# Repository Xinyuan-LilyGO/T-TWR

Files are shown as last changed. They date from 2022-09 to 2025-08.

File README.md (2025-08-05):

<h1 align = "center">🌟 LILYGO T-TWR 🌟</h1>




## News

#### There are the following differences between Rev2.1 and Rev2.0

1. Rev2.1 has a microphone switching matrix that can collect microphone signals for processing by ESP32S3, but Rev2.0 does not.
2. Rev2.1 has a speaker switching matrix, which can send audio signals to the power amplifier to play prompts, music, etc. through the switching matrix. Rev2.0 does not have it.
3. Rev2.1 has an IO switching matrix, and SA8X8 can be programmed through the switching matrix. Rev2.0 does not have this feature. This feature was proposed by the OpenRTX team. The function is not yet implemented. Please pay attention to OpenRTX for the latest progress.
4. Rev2.1 can determine whether the device address is UHF or VHF through OLED, but Rev2.0 cannot.
5. Rev2.1 can obtain whether the SA8X8 is currently in the receiving state by monitoring IO2, but Rev2.0 cannot..
6. In Rev2.1, the PTT button is changed to the left side, which is closer to the real walkie-talkie operating habits, while in Rev2.0, it is on the right side.
7. Rev2.1 changes the pixel light to the upper right to make it easier to monitor the status, Rev2.0 is on the side of the PCB
8. Rev2.1 reserves the RF front-end matching circuit, which makes it easier to fine-tune the signal.
9. The Rev2.1 RF module power supply is changed to direct battery power supply. Compared with the Rev2.0 DC power supply method, the power supply noise is minimized and can provide better RF performance.

## 1️⃣Support Product

| Product(PinMap) | SOC | Flash | PSRAM |
| --- | --- | ----- | --- |
| [T-TWR Rev2.0][1] | ESP32-S3R8 | 16MB  | 8MB(OPI) |
| [T-TWR Rev2.1][2] | ESP32-S3R8 | 16MB  | 8MB(OPI) |

[1]: https://www.lilygo.cc/products/t-twr-plus
[2]: https://www.lilygo.cc/products/t-twr-rev2-1

## 2️⃣Examples

```txt
examples/
├── Factory                         # TWR Factory Application
├── GPS_Basic_Example               # GPS example
├── GPS_Full_Example                # GPS example
├── Pixels_RGBWstrandtest           # Pixels example
├── Pixels_Strandtest_Example       # Pixels example
├── SA868_ATDebug_Example           # Radio  AT Debug example
├── SA868_ESPSendAudio_Example      # Radio frequency sends ESP32 signal
├── SD_Test_Example                 # SD Test Example
├── SD_Time_Example                 # SD Time Example
├── WAV_Player                      # WAV Player
├── TFT_ArcFill_Example             # Screen extension example
├── TFT_Keypad_240x320_Example      # Screen extension example
├── U8g2_FontUsage_Example          # Onboard OLED U8G2 example
├── U8g2_GraphicsTest_Example       # Onboard OLED U8G2 example
└── U8g2_UpdateArea_Example         # Onboard OLED U8G2 example
```

## 3️⃣ PlatformIO Quick Start

1. Install [Visual Studio Code](https://code.visualstudio.com/) and [Python](https://www.python.org/)
2. Search for the `PlatformIO` plugin in the `VisualStudioCode` extension and install it.
3. After the installation is complete, you need to restart `VisualStudioCode`
4. After restarting `VisualStudioCode`, select `File` in the upper left corner of `VisualStudioCode` -> `Open Folder` -> select the `T-TWR` directory
5. Click on the `platformio.ini` file, and in the `platformio` column, cancel the sample line that needs to be used, please make sure that only one line is valid
6. Click the (✔) symbol in the lower left corner to compile
7. Connect the board to the computer USB
8. Click (→) to upload firmware
9. Click (plug symbol) to monitor serial output

## 4️⃣ Arduino IDE Quick Start

1. Install [Arduino IDE](https://www.arduino.cc/en/software)
2. Install [Arduino ESP32](https://docs.espressif.com/projects/arduino-esp32/en/latest/)
3. Copy all the folders in the `T-TWR/lib` directory to `<C:\Users\UserName\Documents\Arduino\libraries>`. If there is no `libraries` directory, please create a new one. Please note that you are not copying the `lib` directory, but copying the folders in the lib directory
4. Open ArduinoIDE -> `Tools`
    | Arduino IDE Setting                  | Value                             |
    | ------------------------------------ | --------------------------------- |
    | Board                                | **ESP32S3 Dev Module**            |
    | Port                                 | Your port                         |
    | USB CDC On Boot                      | Enable                            |
    | CPU Frequency                        | 240MHZ(WiFi)                      |
    | Core Debug Level                     | None                              |
    | USB DFU On Boot                      | Disable                           |
    | Erase All Flash Before Sketch Upload | Disable                           |
    | Events Run On                        | Core1                             |
    | Flash Mode                           | QIO 80MHZ                         |
    | Flash Size                           | **16MB(128Mb)**                   |
    | Arduino Runs On                      | Core1                             |
    | USB Firmware MSC On Boot             | Disable                           |
    | Partition Scheme                     | **16M Flash(3M APP/9.9MB FATFS)** |
    | PSRAM                                | **OPI PSRAM**                     |
    | Upload Mode                          | **UART0/Hardware CDC**            |
    | Upload Speed                         | 921600                            |
    | USB Mode                             | **CDC and JTAG**                  |
    * The options in bold are required, others are selected according to actual conditions.
5. Insert USB into the PC and click Upload <If the upload fails, View the FAQ below>

## 5️⃣ FAQ

1. ⚠⚠⚠ **Precautions (special matters)**:
    1. The **glue stick (RF) antenna** must be connected. If the antenna is not connected, the RF module may be damaged, and the PMU will automatically turn off the power output
    2. A separate USB power supply may not meet the power supply requirements, please connect the battery to use , **The Rev2.1 version must use a battery to power the radio frequency unit and cannot use USB to work alone (because the RF current is very large and the noise can be minimized using battery power)**
    3. Please note that when adjusting to high power transmission, please ensure that the battery has sufficient discharge capacity, otherwise the PMU will automatically shut down due to insufficient current.
    4. TWR Rev2.0 has two versions, one comes with NiceRF AT firmware, and the other is a community version without any functions. For the community version, please jump to [OpenRTX](https://github.com/OpenRTX/OpenRTX) to burn [OpenRTX SA8x8 firmware](https://github.com/OpenRTX/sa8x8-fw) for use. For novices, it is recommended to use NiceRF firmware.
    5. TWR Rev2.1 is version agnostic. The built-in NiceRF firmware can be flashed to OpenRTX firmware, but the NiceRF firmware cannot be restored after flashing.

2. Radio extremely hot when sending?
      1. If the power level is set to high, then the current consumption is huge and the efficiency is very low. It is not recommended to use high power because the difference between high and low power is very small, but the difference in current consumption is very large. You can check the comparison here

      | Voltage | Freq | High transmit power                    | Low transmit power                   |
      | ------- | ---- | -------------------------------------- | ------------------------------------ |
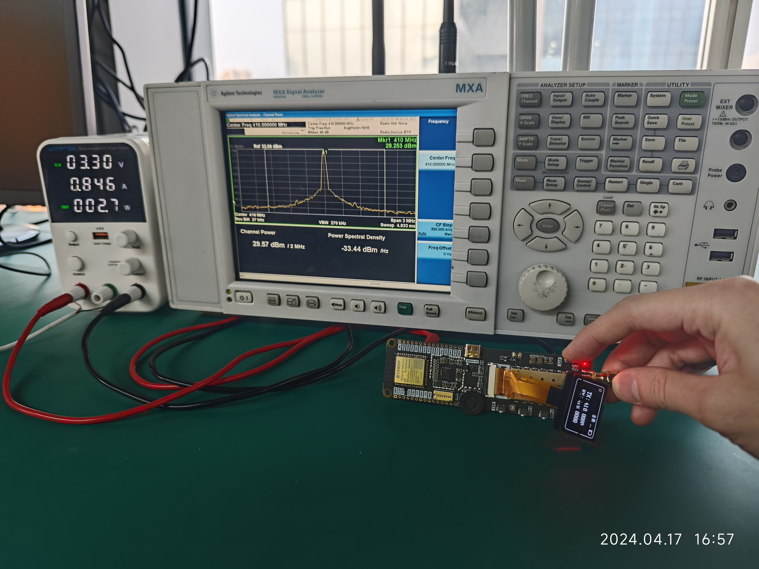
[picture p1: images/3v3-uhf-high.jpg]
UHF_HIGH
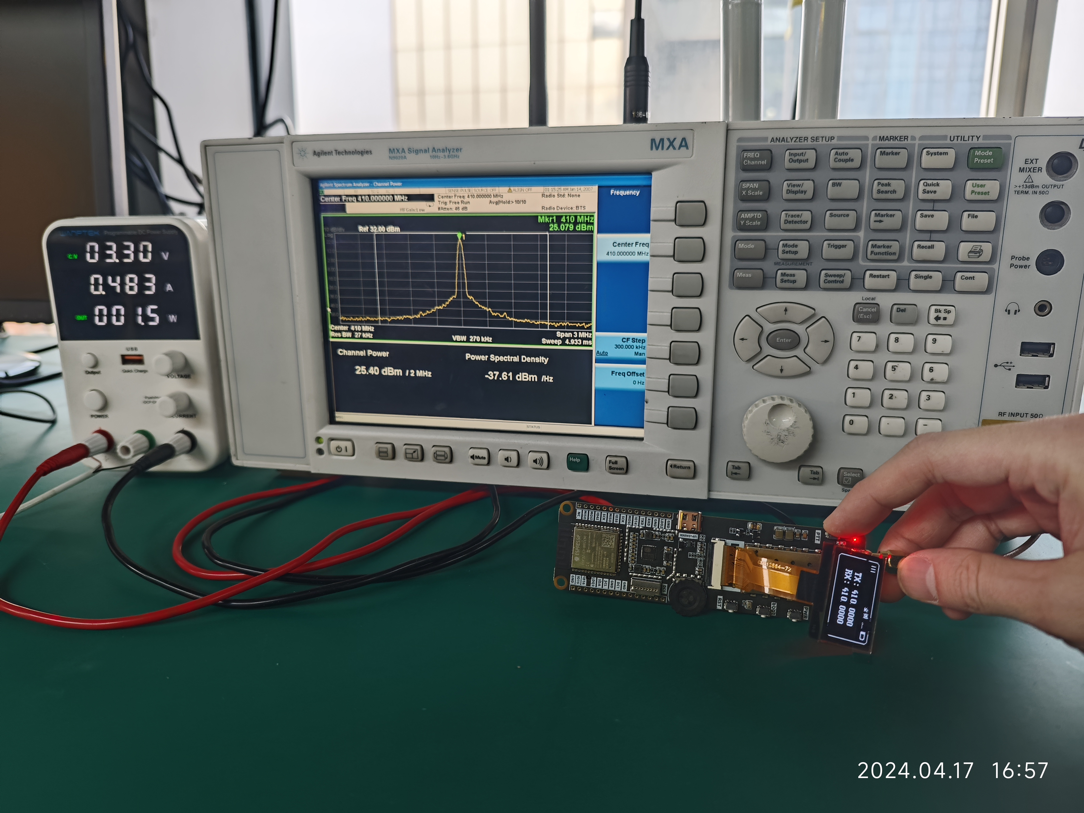
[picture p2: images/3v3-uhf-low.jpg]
      | 3.3V    | UHF  |  |  |
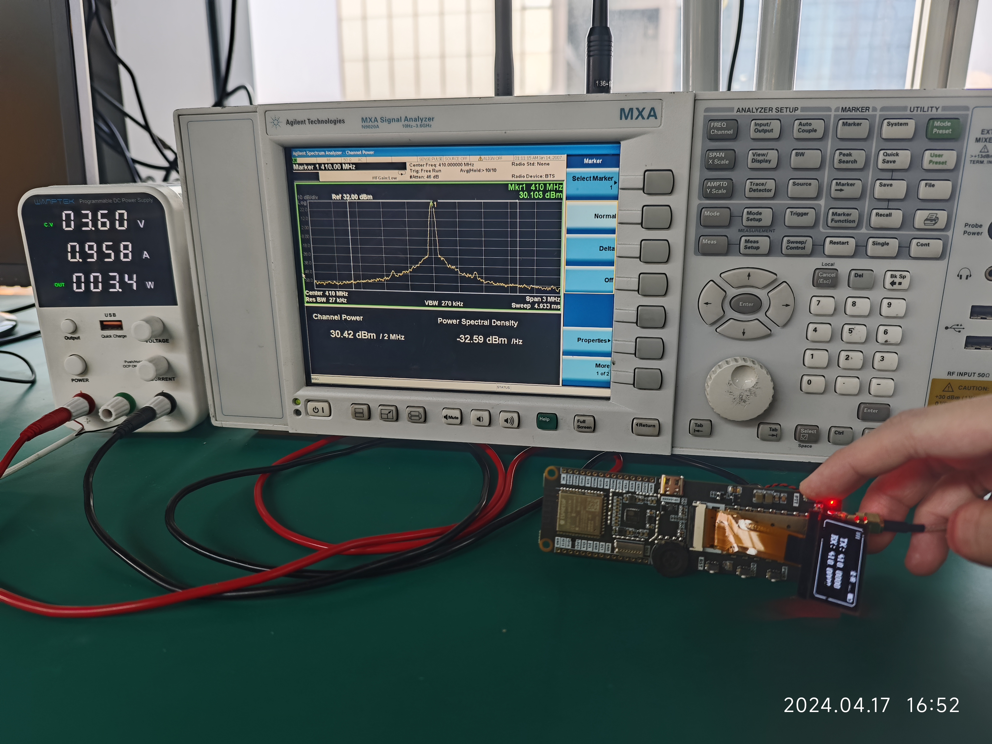
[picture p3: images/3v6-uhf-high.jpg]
UHF_HIGH
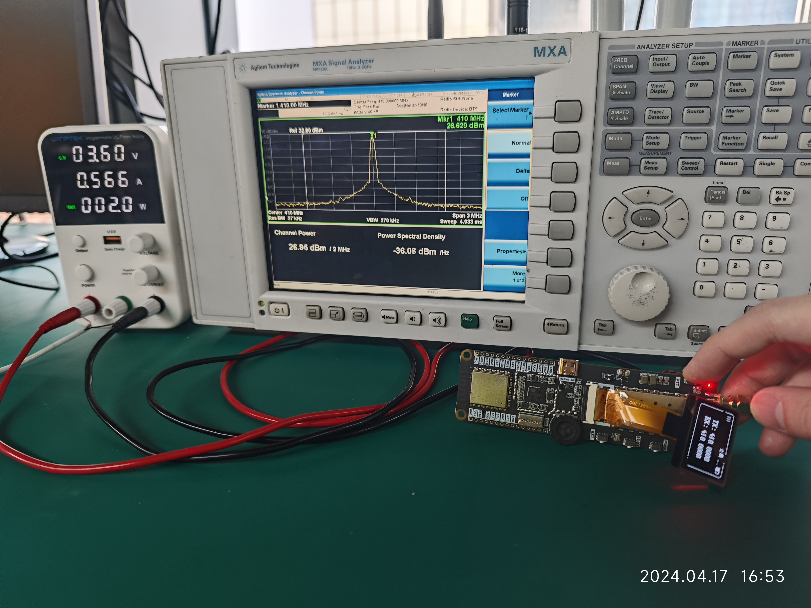
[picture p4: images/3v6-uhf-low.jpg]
      | 3.6V    | UHF  |  |  |
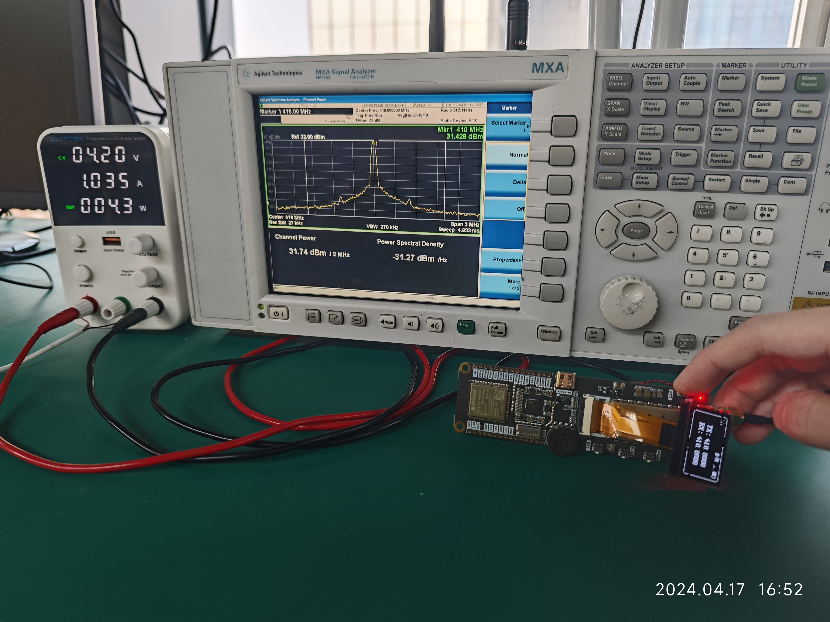
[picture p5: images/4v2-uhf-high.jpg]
UHF_HIGH
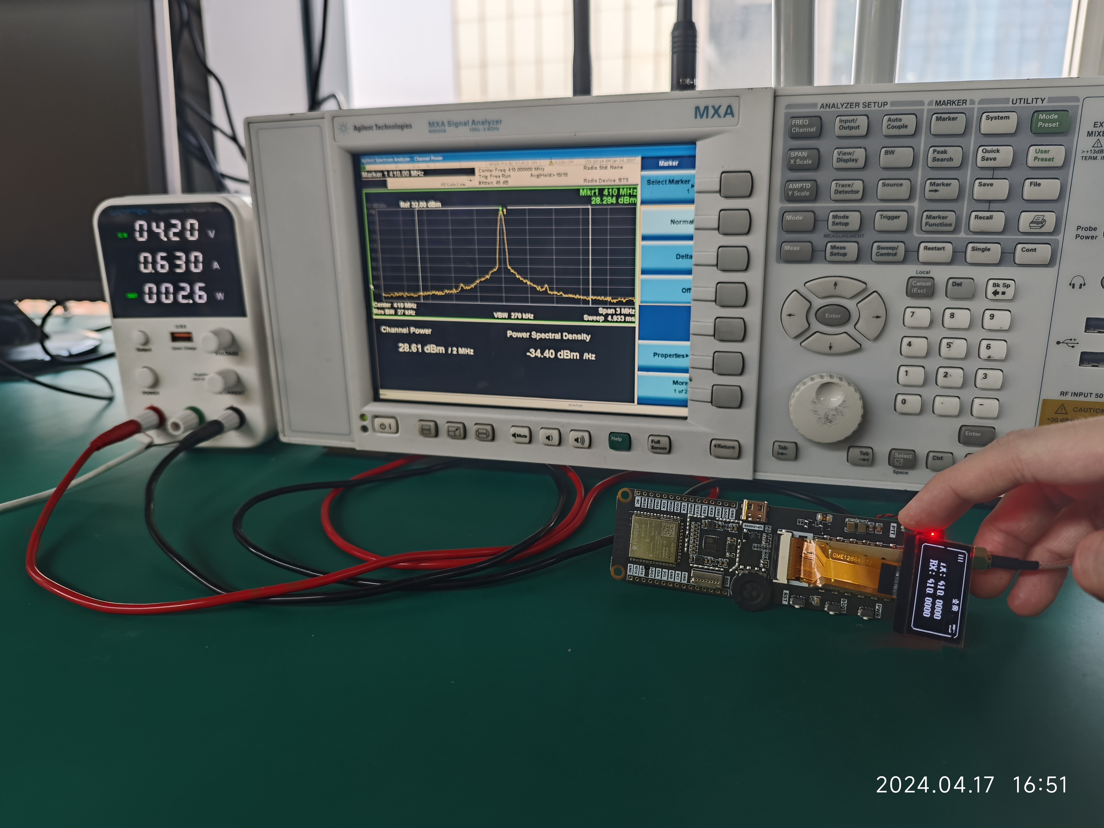
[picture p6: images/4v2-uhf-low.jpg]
      | 4.2V    | UHF  |  |  |
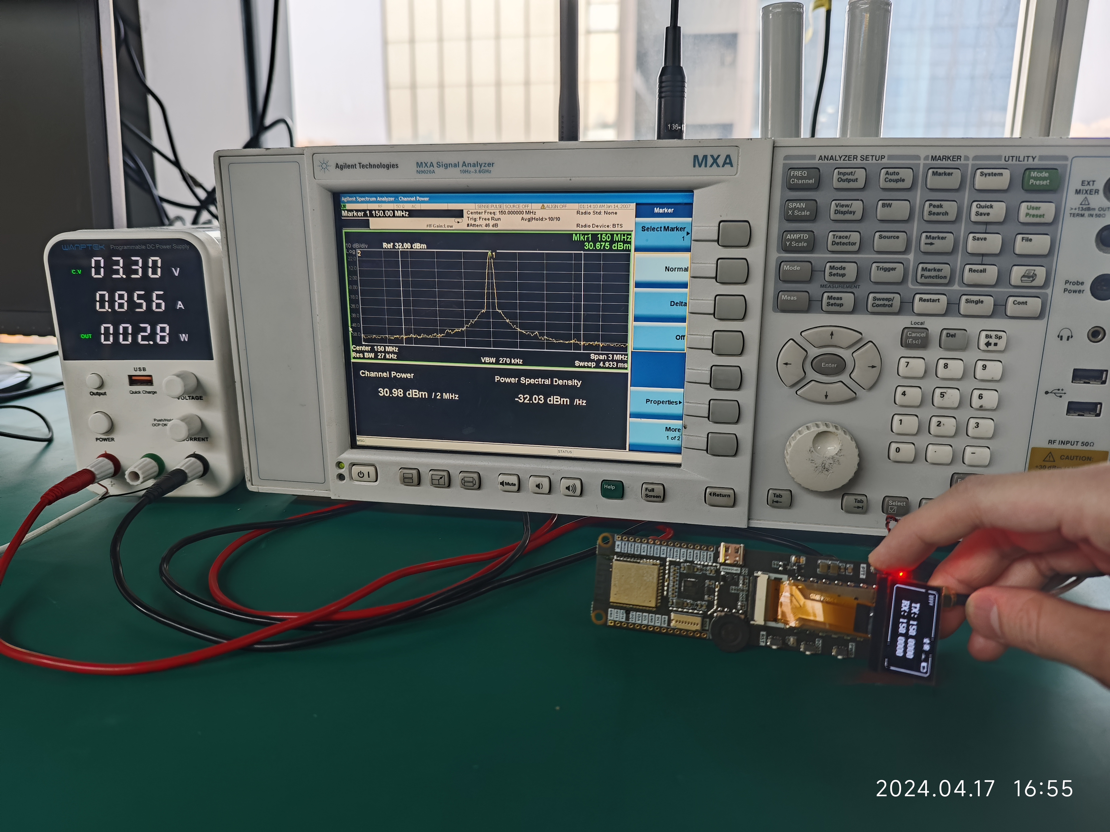
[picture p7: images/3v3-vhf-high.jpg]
VHF_HIGH
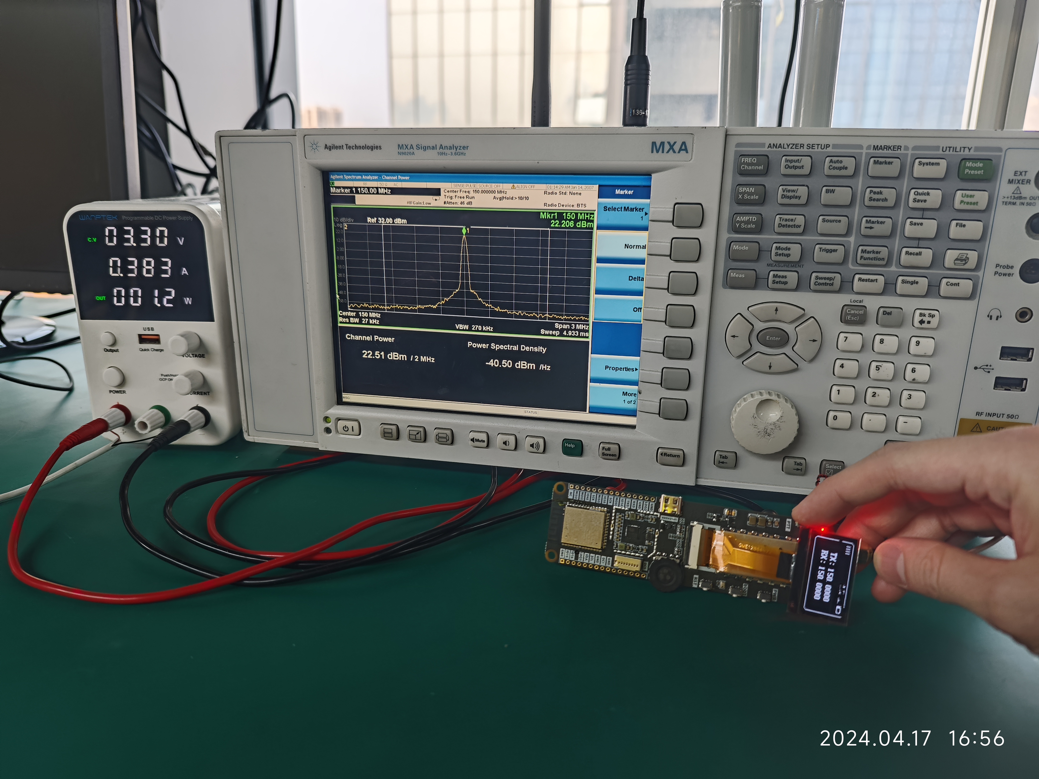
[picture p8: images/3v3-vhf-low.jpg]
      | 3.3V    | VHF  |  |  |
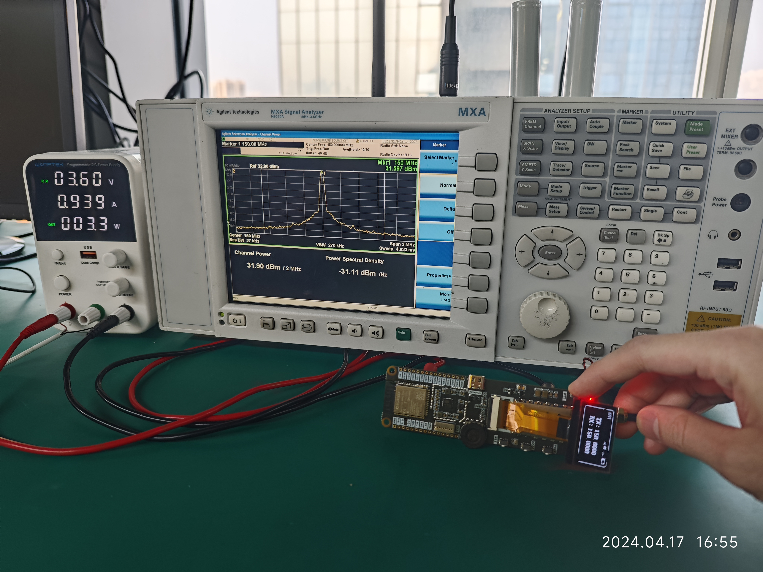
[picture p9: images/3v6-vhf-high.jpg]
VHF_HIGH
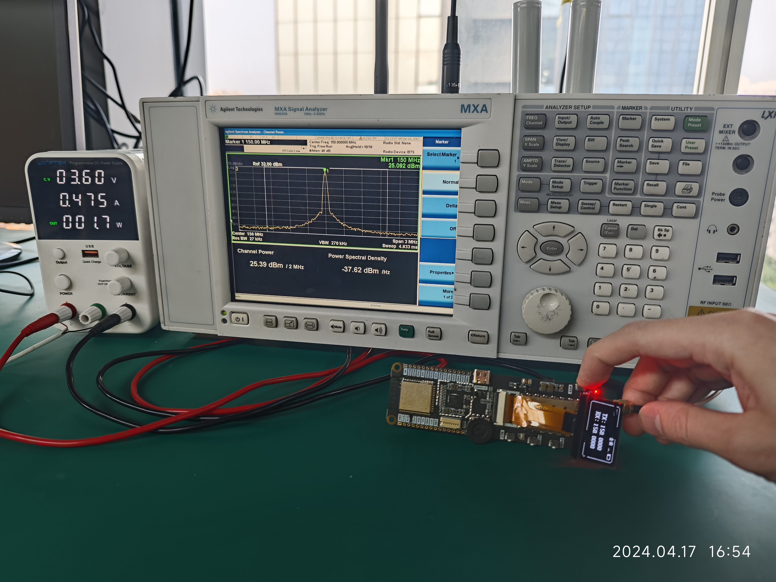
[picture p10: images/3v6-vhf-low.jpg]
      | 3.6V    | VHF  |  |  |
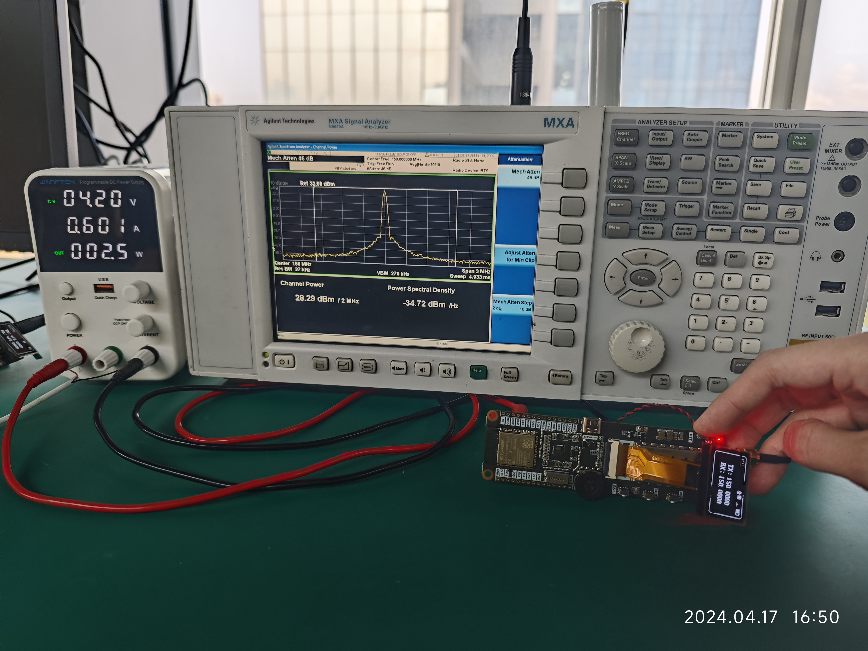
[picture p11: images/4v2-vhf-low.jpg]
      | 4.2V    | VHF  |   | VHF_LOW |

 3. ⚠ **Unable to download the program, the error is shown below.**
      <details>
      <summary>
      Click to view detailed steps
      </summary>

      ```shell
      Flash: [====      ]  35.7% (used 467813 bytes from 1310720 bytes)
      Configuring upload protocol...
      AVAILABLE: cmsis-dap, esp-bridge, esp-builtin, esp-prog, espota, esptool, iot-bus-jtag, jlink, minimodule, olimex-arm-usb-ocd, olimex-arm-usb-ocd-h, olimex-arm-usb-tiny-h, olimex-jtag-tiny, tumpa
      CURRENT: upload_protocol = esptool
      Looking for upload port...
      Auto-detected: COM236
      Uploading .pio\build\uhf_band\firmware.bin
      esptool.py v4.5
      Serial port COM236
      Connecting...

      A serial exception error occurred: ClearCommError failed (PermissionError(13, 'The device does not recognize the command.', None, 22))
      Note: This error originates from pySerial. It is likely not a problem with esptool, but with the hardware connection or drivers.
      For troubleshooting steps visit: https://docs.espressif.com/projects/esptool/en/latest/troubleshooting.html
      *** [upload] Error 1
      ================================================================================================================ [FAILED] Took 8.75 seconds ================================================================================================================

      ```
      - Step
      - Press the **PWR** button for one second to make sure the TWR is powered on
      - Press and hold the **BOOT** button (without releasing it), then press the **RST** button, then release the **RST** button, and finally release the **BOOT** button
      - Click the upload button in the IDE and wait for the upload to complete
      - Press the **RST** button to exit the download mode
      
      </details>

3. ⚠ **Can I change the voltage of the peripheral?**
      <details>
      <summary>
      Click to view detailed steps
      </summary>
        1. Not recommended, changing the peripheral voltage may cause abnormal operation, please do not change the default voltage setting of the peripheral, please refer to the voltage setting in the sample program.
      </details>

4. ⚠ **Why can't I test the charging current to reach the set current?**
      <details>
      <summary>
      Click to view detailed steps
      </summary>
       1. If you use a USBC cable with low quality or too large or too long wire resistance, there will be a large internal resistance, and there is no rated 5V input on the board, so the PMU will think that the power supply voltage is insufficient, so the rated charging current cannot be reached. ,The solution is to replace the high-quality USBC wire, reduce the length of the wire to meet the requirements of the PMU input voltage<br>
       2. You can measure the voltage at both ends of the figure below to see if it can meet the 5V input voltage required by the PMU<br>
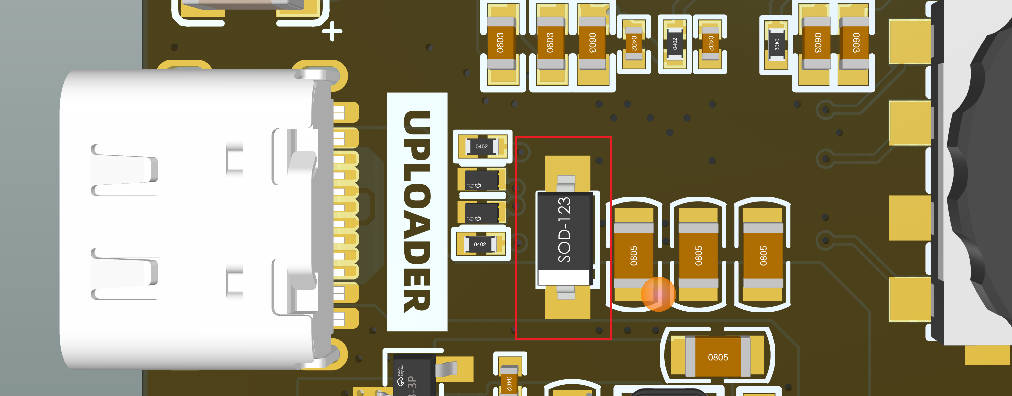
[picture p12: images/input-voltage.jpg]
         

      1. Please note that if the charging current is set to 1A, please install a suitable heat sink above the PMU to reduce the risk of heat and damage caused by overheating.
      </details>

5.  ⚠  When you think there is a problem with the board, you can try to burn our [factory firmware](./firmware/README.MD) for testing, you can first rule out whether it is a hardware problem

6. ⚠ **I don’t have a **21700 battery**, can I replace the battery holder with a **18650** battery holder?**
      <details>
      <summary>
      Click to view detailed steps
      </summary>
      1. The board is compatible with 21700 and 18650 battery holders, if you have the ability to replace it, please note that **LilyGo does not bear the risk of replacing the battery holder without authorization, damage and Brought to work abnormally**
      </details>

7. ⚠ **Can't turn on automatically after connecting the battery?**
      <details>
      <summary>
      Click to view detailed steps
      </summary>
      1. Connect the battery separately, you need to press the **PWR button** for one second, the board will start the action, press and hold the **PWR** button for 6 seconds to shut down, the shutdown time can be set by software , In the latest version (Rev2.1), inserting the battery will automatically power on.
      </details>

8. TWR currently has two modes before leaving the factory, one is flashed with regular firmware and uses the esp built-in boot, and the other uses TinyUF2 as the boot program. For novices, please [see here](./firmware/README.MD)

9.  How to enter TinyUF2 boot mode?

      <br>

      <details>
      <summary>
      Click to view detailed steps
      </summary>
       1. Before entering TinyUF2, the boot program must have been flashed. If it has not been written, please see here https://github.com/Xinyuan-LilyGO/T-TWR/blob/master/firmware/README.MD <br>
       2. Press the RST button<br>
       3. After pressing the RST button for one second, press the BOOT button. The disk will be ejected on the computer.<br>
       4. At this time, drag the firmware with the suffix uf2 into the disk to upgrade the device.<br>
      </details>
11. ⚠ **There is a microphone port on the bottom of the board, do I need to install a microphone? Only for Rev2.0, Rev2.1 has removed the external microphone interface**
      <details>
      <summary>
      Click to view detailed steps
      </summary>
      1. No, there is already a condenser microphone on board. If you need to use a wired microphone, please remove the board microphone. Please note that **LilyGo will not be responsible for the damage and abnormality of the board caused by unauthorized disassembly of the microphone**
      </details>

12. Sleep power consumption (**Rev2.1**), taking the Factory example as a reference, the deep sleep current is about **680uA**
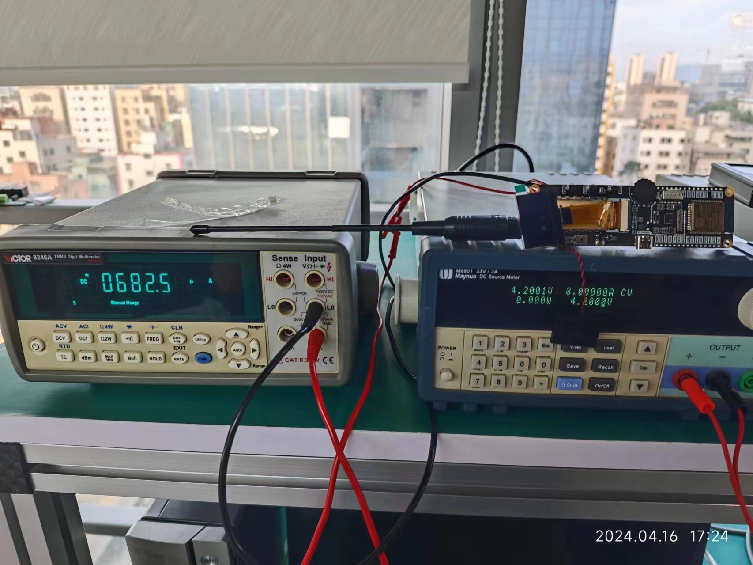
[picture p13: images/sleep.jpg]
      <br>

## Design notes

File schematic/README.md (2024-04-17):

# Schematic

| Version Information | Schematic |
| --- | --- |
| T-TWR Plus Rev 2.0 | [T-TWR_Plus Rev2.0](T-TWR-Plus_Rev2.0.pdf) |
| T-TWR Plus Rev 2.1 Preview | [T-TWR-Plus_Rev2.1-Preview](T-TWR-Plus_Rev2.1-Preview.pdf) |
| T-TWR Plus Rev 2.1 | [T-TWR_Plus Rev2.1](T-TWR-Plus_Rev2.1.pdf) |

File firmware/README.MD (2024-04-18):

# News
  
* For TWR Rev2.1, there is no need to distinguish between UHF or VHF, you can write directly to twr_Rev2.x.bin or **twr_Rev2.x.uf2**
* TWR Rev 2.0 can also be written to **twr_Rev2.x.bin** or **twr_Rev2.x.uf2**. The default is UHF. UHF or VHF can be selected through the menu.

# 1️⃣ Regular firmware

| FileName | Firmware |
| --- | --- |
| twr_Rev2.0_uhf.bin | [firmware](./twr_Rev2.0_uhf.bin) |
| twr_Rev2.0_vhf.bin | [firmware](./twr_Rev2.0_vhf.bin) |
| twr_Rev2.x.bin | [firmware](./twr_Rev2.x.bin) |
| twr_gps_debug.bin  | [firmware](./twr_gps_debug.bin)  |

## How falsh *.bin file ?

1. [Win10 Flash method](https://github.com/Xinyuan-LilyGO/LilyGo-Document/blob/master/WinFlashBin.md)
2. [Mac & Liunx Flash method](https://github.com/Xinyuan-LilyGO/LilyGo-Document/blob/master/MacFlashBin.md)

# 2️⃣ TinyUF2 firmware

| FileName | Firmware |
| --- | --- |
| tinyuf2_bootloader.bin | [firmware](./tinyuf2_bootloader.bin) |
| twr_Rev2.0_uhf.uf2 | [firmware](./twr_Rev2.0_uhf.uf2) |
| twr_Rev2.0_vhf.uf2 | [firmware](./twr_Rev2.0_vhf.uf2) |
| twr_Rev2.x.uf2 | [firmware](./twr_Rev2.x.uf2) |
| twr_gps_debug.uf2 | [firmware](./twr_gps_debug.uf2) |

* To use TinyUF2, you need to burn tinyuf2_bootloader.bin first. After the burning is completed, a disk will pop up. Drag firmware.uf2 into the disk.

## How to use ArduinoIDE to flash firmware again?

* After using TinyUF2, a virtual port will be generated and cannot be written directly using ArduinoIDE. The TWR must be put into download mode before the actual physical port will be displayed.
  
## How to put TWR into download mode

* Press the **PWR** button for one second to make sure the TWR is powered on
* Press and hold the **BOOT** button (without releasing it), then press the **RST** button, then release the **RST** button, and finally release the **BOOT** button
* Click the upload button in the IDE and wait for the upload to complete
* Press the **RST** button to exit the download mode

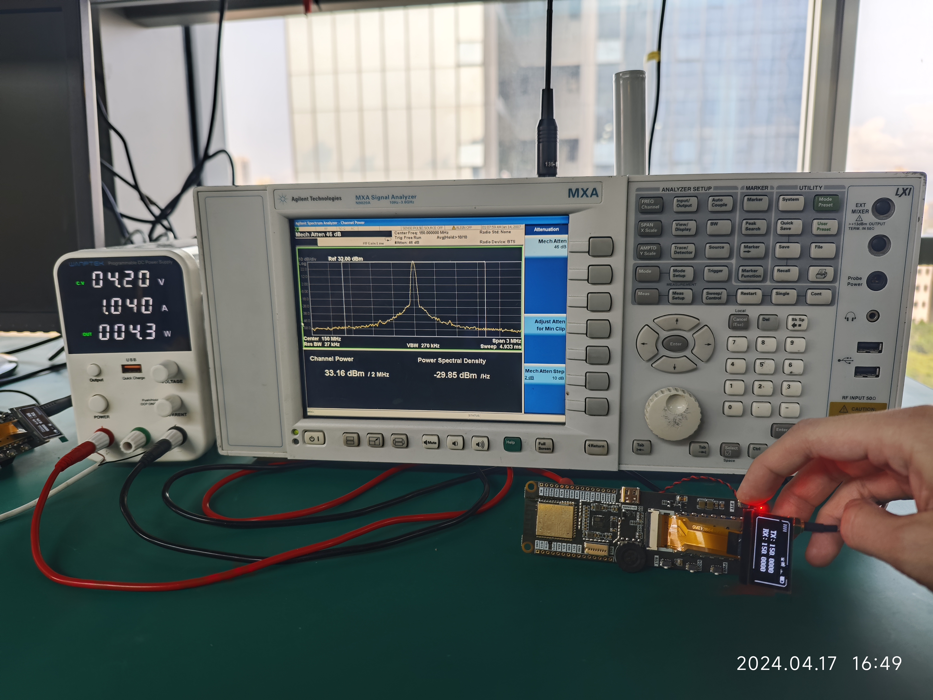
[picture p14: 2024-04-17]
images/4v2-vhf-high.jpg

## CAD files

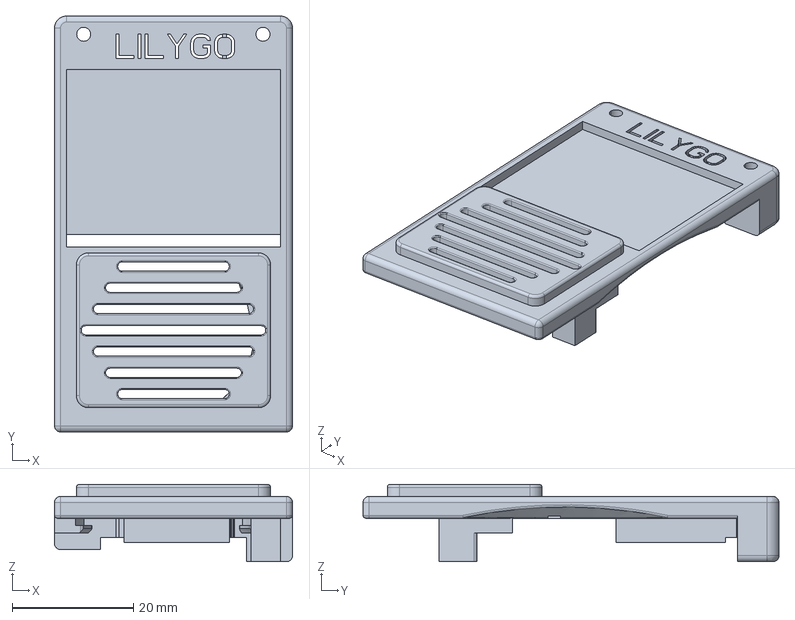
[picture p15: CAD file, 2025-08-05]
dimensions/TWR-Plus-Rev2.1-Display-shell.stp
39.2 x 68.5 x 12.8 mm

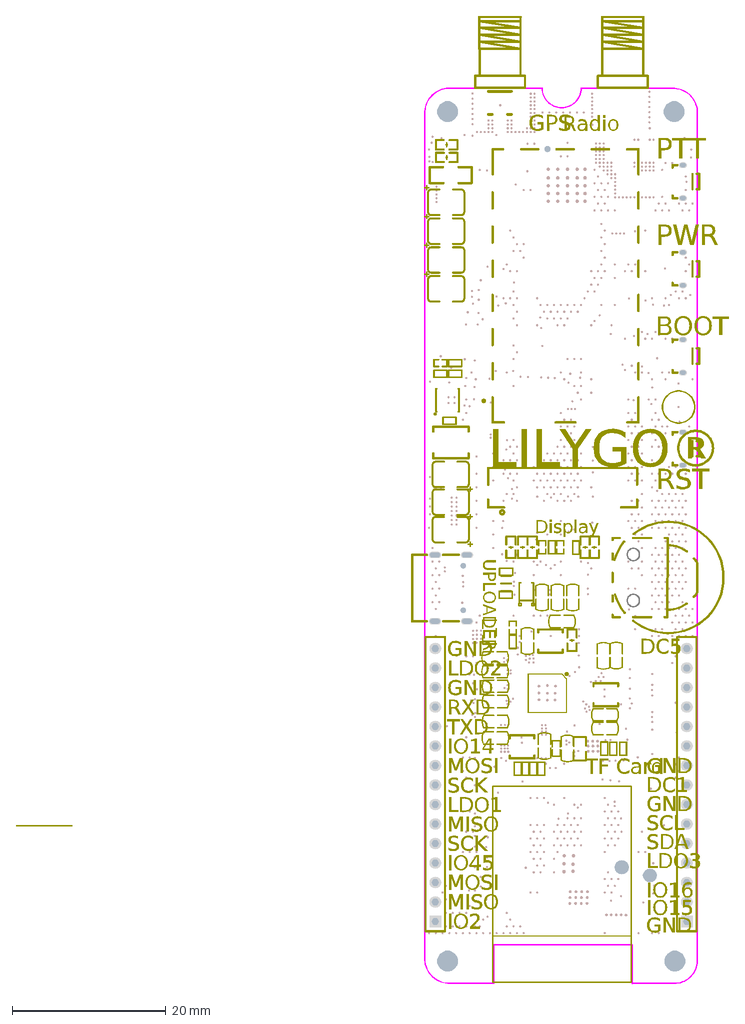
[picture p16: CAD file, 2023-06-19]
dimensions/TWR_Plus_Rev2_0.DXF
BOOT
TF Card
MOSI
GND
PTT
DC1
IO14
LDO1
SCK
SCL
IO2
MISO
RXD
LDO2
Display
UPLOADER
IO15
SDA
TXD
Radio
IO45
LILYGO®
RST
GPS
DC5
IO16
PWR
LDO3

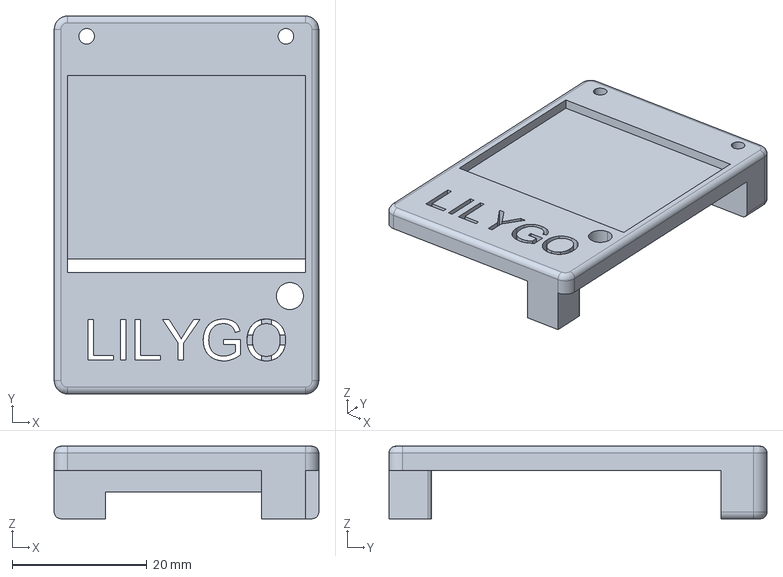
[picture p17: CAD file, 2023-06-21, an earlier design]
dimensions/TWR-Plus-Display-shell.stp
39.2 x 56.0 x 10.8 mm

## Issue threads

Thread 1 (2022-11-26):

ADC (SPK)  and DAC (MIC) feature request

lyusupov, 2022-11-26:
&nbsp;&nbsp; &nbsp; &nbsp;  Dear LilyGO T-TWR product developer !

Thank you very much for the idea and development of the T-TWR !

This message is actually not an issue report but a minor feature request...

I am not able to see the product schematics but can inspect the picture that was recently published on LilyGO Twitter account:

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

On this picture I can not see any electronic elements that would prove a statement that MIC and SPEAKER pads of the SA868 module are connected to the ESP32-S3 ADC/DAC ones.
So I assume that they are connected directly to the microphone and speaker components only, right?

If this is true - I have a minor design improvement proposal to you:
Could you, please, add few circuits to wire MIC and SPEAKER pads of the SA868 module to  ADC/DAC pads of the ESP32-S3 ?

There is a great project on GitHub https://github.com/erstec/APRS-ESP
that uses both SA868  and ESP32 where:
*  ESP32 can supply signal to SA868 (DAC to MIC) and
*  ESP32 can read signal from SA868 (SPK to DAC)

This is an excerpt of the schematics that you can use as a reference:

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

While having this feature available, we can:
* record the received radio signal into 16 Mbytes flash memory of the ESP32-S3 module and/or
* play sound recordings from flash memory and transmit them into the RF air

    Best regards,
    Linar.

lbuque, 2022-12-10:
Hi,
Presumably you have received the schematic diagram of T-TWR!

Your idea is great, but whether those functions will be added needs confirmation from the leadership!

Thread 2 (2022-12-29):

T-TWR RF module connect audio to ESP32

redfast00, 2022-12-29:
Hi! I'd be really excited to use the T-TWR module for digital HAM radio projects (for example as an APRS modem). Is the RF chip directly connected to the microphone/speaker? Is it possible to send and receive audio waveforms from/to the ESP32?

redfast00, 2022-12-29:
This would for example also make it possible to build an internet-connected radio repeater

lbuque, 2022-12-30:
> Is the RF chip directly connected to the microphone/speaker?

yes.

> Is it possible to send and receive audio waveforms from/to the ESP32?

Newer hardware may support it.

lyusupov, 2023-05-27:
> Is it possible to send and receive audio waveforms from/to the ESP32?

https://github.com/Xinyuan-LilyGO/T-TWR/blob/master/schematic/T-TWR-Plus_Rev2.0.pdf

> excited to use the module for digital HAM radio projects (for example as an APRS modem)

https://github.com/erstec/APRS-ESP

Closed 2024-02-11.

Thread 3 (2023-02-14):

T-TWR 3D model case and schematic

kkwestt, 2023-02-14:
Please add T-TWR 3D model case and schematic. Thx

lbuque, 2023-02-16:
@kkwestt The schematic diagram has been uploaded, and the 3d model still needs time.

F4VSJ, 2023-04-18:
Well since February 16th, still no 3d printable case available?
I'm not able to design, sorry

lewisxhe, 2023-04-21:
Currently, there is still no

EasyOne2030, 2024-01-07:
**T-TWR 3D model case ?**

Closed 2024-02-21.

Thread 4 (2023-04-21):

print_wakeup_reason' was not declared in this scope

EasyOne2030, 2023-04-21:
exit status 1
'print_wakeup_reason' was not declared in this scope
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

lewisxhe, 2023-04-22:
Add this line above the sketch

void print_wakeup_reason();

EasyOne2030, 2023-04-22:
The problem is not solved !
exit status 1
'app_nvs_init' was not declared in this scope

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

lewisxhe, 2023-04-22:
Already fixed.

https://github.com/Xinyuan-LilyGO/T-TWR/commit/1597e8b1bccb8b3283aace25060cdb846f4086b7

Closed 2023-04-22.

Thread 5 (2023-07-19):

PTT button is not turn on transmission

nmuntyanov, 2023-07-19:
Hello, guys!
I've bought TWR Plus 2.0 VHF version, and found few bugs (or not, not shure)

1 transmit/receive frequency can't be changed with encoder via settings menu
I have build firmware in debug mode, and see that new frequency is sent to SA868 but there is still old one on LCD screen

2 there is no transmission when PTT button is pressed
I have added Serial.print in void SA868::transmit() function to be able to debug that it is invoked and it does, but no transmission happened (I have SDR to monitor)

Is anyone have such issues? Any solutions?

And one more thing, how can i suppress such log types:
```
$GNGSA,A,3,09,14,42,,,,,,,,,,5.1,3.8,3.4,4*36
$GPGSV,2,1,06,07,39,061,19,08,12,052,23,09,12,119,30,13,42,305,,0*6D
$GPGSV,2,2,06,14,60,156,33,15,11,306,,0*63
$BDGSV,1,1,03,09,12,0840,E,1,07,3.8,605.8,M,43.9,M,,*4F
$GNGLL,4238.92078,N,02322.91040,E,200244.000,A,A*43
$GNGSA,A,3,07,08,09,14,,,,,,,,,5.1,3.8,3.4,1*3A
$GNGSA,A,3,09,14,42,,,,,,,,,,5.1,3.8,3.4,4*36
$GPGSV,2,1,06,07,39,061,19,08,12,052,25,09,11,119,30,13,42,305,,0*68
$GPGSV,2,2,06,14,60,156,33,15,11,306,,0*63
$BDGSV,1,1,03,09,12,082,23,14,49,162,31,42,24,152,39,0*45
$GNRMC,200244.000,A,4238.92078,N,02322.91040,E,0.31,0.00,180723,,,A,V*03
```
they are not informative for me now

amoxu, 2023-07-19:
The logs are from GPS module.

When you placed the order,  Which edition you selected? open edition or standard edition?

nmuntyanov, 2023-07-19:
> The logs are from GPS module.
>
> When you placed the order, Which edition you selected? open edition or standard edition?

I've bough here https://www.aliexpress.com/item/1005005734253889.html
OpenEdition VHF
Order placed on: Jun 29, 2023

nmuntyanov, 2023-07-19:
But there is no "OpenEdition" word on box
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
what is the difference?

amoxu, 2023-07-19:
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

You need to read about the NOTICE on the product page,  Open edition is a special edition which with blank RF module,  It will be useful only after open source firmwares released,  Which are under very early development stage.

Welcome to pay attention to the progress of M17 and OPENRTX projects.

nmuntyanov, 2023-07-19:
Got it! Thank you.
Do you have links on this projects?

amoxu, 2023-07-19:
> Got it! Thank you.
> Do you have links on this projects?

https://discord.gg/k4deHPZy

nmuntyanov, 2023-07-19:
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

Thank you. I thought there are no firmware for sa868 at all
Can I somehow burn it into module without soldering it?
As I understand module is Connected to only ESP32 by UART?
Can it be programmed in-system?

nmuntyanov, 2023-07-19:
> Thank you. I thought there are no firmware for sa868 at all Can I somehow burn it into module without soldering it? As I understand module is Connected to only ESP32 by UART? Can it be programmed in-system?

I guess, i found
It seems CN4 socket is for sa868 programming

amoxu, 2023-07-21:
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

Yes, for more details, please refer to the discussions in the discord channel.

nmuntyanov, 2023-07-29:
> https://discord.gg/k4deHPZy

May you send me new invite? Old one is expired
I had some issues with my discord account before.

amoxu, 2023-07-30:
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

https://discord.gg/K4y5DxeBG

you can also following matrix space:
https://matrix.to/#/#openrtx:matrix.org
All the messages are synchronized between matrix and discord.

Closed 2023-07-19.

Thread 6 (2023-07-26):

Programming issue

itay-grudev, 2023-07-26:
I have two T-TWR, rev 1 and I can't program any of them.

I followed your reset procedure in the troubleshooting section, but when I do that the serial device disappears from the USB Device list.

Do you have any other advice?

lyusupov, 2023-07-27:
> **T-TWR, rev 1** , I can't program any of them.

- https://t-twr.readthedocs.io/en/latest/troubleshooting.html#sa868-power-problem
- https://docs.espressif.com/projects/esp-idf/en/latest/esp32s3/api-guides/jtag-debugging/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

itay-grudev, 2023-07-29:
@lewisxhe As I said, when I follow that procedure the device disappears from the USB. It's very strange and I can't upload anything.

SensorsIot, 2023-08-22:
My two boards also create lots of problems. If I follow your advice and reset it with GPIO0 pressed, the board draws 1.7A, and the SA868 gets extremely hot (but no output power on RF). I managed to program one board using RX/TX pins. The other one only creates brownouts (also with a battery attached).

lyusupov, 2023-08-25:
Version **1**.x of T-TWR uses GPIO39 to drive H/L pin of SA868 module.
Unfortunately, it is not well documented by Espressif that GPIO39 has hardware  pull up after reset to meet some JTAG MTCK purpose requirements.

https://www.esp32.com/viewtopic.php?f=12&p=111105

This _(not well documented)_ pull-up state can cause an excessive heat of SA868 module until it is explicitly set to LOW by a customer's firmware.
**LilyGO factory firmware pulls the GPIO39 down at very first steps of it's initialization sequence**.

OpenOCD firmware uploading method is knowing good to operate with T-TWR 1.3:
https://docs.espressif.com/projects/esp-idf/en/latest/esp32s3/api-guides/jtag-debugging/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

**This issue is not applicable for version 2.x** of the T-TWR which is also known as **T-TWR Plus**.

Here is an example of the **T-TWR Plus** operating as [**APRS Beacon**](https://en.wikipedia.org/wiki/Automatic_Packet_Reporting_System) device.
https://drive.google.com/file/d/18a2PpIE4KQ6lYPcmPZgXnCYFSRYEqKz-/view

A bit more info about this particular use case is available there: https://github.com/lyusupov/SoftRF/wiki/Ham-Edition

SensorsIot, 2023-08-25:
I think that these boards are not fit for purpose and I will throw my 4 pcs into the waste. If you sell such a product with Arduino software it should be programmable with Arduino SW.
The problem with the high current starts when you set the board into the upload status (press boot + reset), which is needed in many cases for programming. I do not exactly know why. Most probably not only because of GPIO39. H/L has no function in the RX mode of the SA868 module.
For all that that want to use them anyway: Use RX/TX for programming instead of USB. Reset the board and wait till the Arduino IDE starts to upload. Then press boot and quickly reset. Now it uploads, and the module warms up. Immediately after upload, reset the board, and if you set PTT and H/L to low, as written above, the board is not boiling. If you set the Arduino parameters correctly, it might even be possible to program it with USB from now on.

lyusupov, 2023-08-25:
> I think that these boards are not fit for purpose

It was reported by LulyGO that the engineer who designed T-TWR **1.3** no longer works for that company. Some online stores may still sell stocks of v1.3 boards remaining...

**T-TWR Plus**  (a.k.a. v2.0) is supported by Adafruit **TinyUF2** bootloader since 0.16.0:
https://github.com/adafruit/tinyuf2/releases/tag/0.16.0
Read this PR for details: https://github.com/adafruit/tinyuf2/pull/337

**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**

Installing a new firmware into T-TWR Plus with pre-installed TinyUF2 is as simple as mouse "drag and drop" in a File Manager.
https://github.com/lyusupov/SoftRF/blob/master/software/firmware/binaries/README.md#esp32-s3

SensorsIot, 2023-08-26:
Unfortunately, this is not entirely true. Just checked and the official Lilygo Store still sells the old version.

SensorsIot, 2023-08-28:
BTW: I just saw your name on my new T-Echo. If you are responsible for it: Congratulations! It should appear in one of my next videos

lyusupov, 2023-08-28:
**T-Echo** is a result of collaboration of **LilyGO** with
- [SoftRF project](https://github.com/lyusupov/SoftRF) and
- [Meshtastic project](https://meshtastic.org/) , https://meshtastic.discourse.group/t/exciting-new-ttgo-board-prototype/1399/50

**Lewis** is the LilyGO leading engineer who were driving force for development of the T-Echo in 2020 / 2021.

https://github.com/Xinyuan-LilyGO/T-TWR/issues/6#issuecomment-1653663379

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

**Lewis** is driving development of T-TWR **V2.x** (a.k.a. Plus) series at this time.

lewisxhe, 2023-08-28:
Hi @SensorsIot ,

If you encounter problems during use, please contact customer service for processing.

iontodirel, 2025-02-08:
does not work for me, and now it's bricked with a blank screen 👎 any idea of alternate ways to flash it?

Closed 2024-02-11.

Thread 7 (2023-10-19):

Frequency tuning

dnwk, 2023-10-19:
For the walkie-talkie example, I am trying to figure out where is it that controls the TX/RX frequency config. I want to be able to tune to 147.240. Currently, if bandwidth is set to 25k, that also make tuning in 25k increment.

SpudGunMan, 2024-02-03:
is this firmware intended for the VHF unit?

SpudGunMan, 2024-03-04:
Boop

lewisxhe, 2024-04-17:
No, it can only be superimposed in increments of 12.5 or 25, which is stated in the specification.

lewisxhe, 2024-04-17:
https://github.com/Xinyuan-LilyGO/T-TWR/blob/master/datasheet/SA868%202W%20Embedded%20walkie%20talkie%20moduleV1.3.pdf

lyusupov, 2024-04-18:
Unlike SA818 and SA828, the **SA868** module _( with NiceRF firmware )_ is a "**12.5 KHz bandwidth only**"  device:

<br>

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

Closed 2024-06-02.

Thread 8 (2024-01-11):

Can't turn on T-TWR 2.0

nmuntyanov, 2024-01-11:
Hello guys! Can you help me, please.

Version:  2.0, Open edition
I have used it a little bit and now i can't turn it on with pwr button with battery installed.
It works with external power supply and I can turn it on/off with button, and even battery level works (in case when battery + external power supply)

What it can be? Should I replace AXP2101?

lewisxhe, 2024-01-11:
Can't turn on when using battery alone?

nmuntyanov, 2024-01-11:
there is some electric noise, PWM i guess, when I press the pwr button

lewisxhe, 2024-01-12:
Do you have a multimeter? After pressing PWR, does DC1 on both sides of the pin header have 3.3V?

lewisxhe, 2024-01-12:
If you have the tools, we can continue to find the problem. If not, please contact customer service to see how to proceed.

nmuntyanov, 2024-01-12:
I have multimeter
Measurements are:
0,52v before and 0,17v after button press

lewisxhe, 2024-01-16:
Hi， @nmuntyanov
What I mean is that after pressing the PWR button, is there 3.3V on the pins marked DC1 on both sides of the TWR?

nmuntyanov, 2024-01-16:
Hi, @lewisxhe
Just to clarify

If you mean this pin
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

No, there is no 3,3v between DC1  and GND after PWR button is pressed

lewisxhe, 2024-01-16:
@nmuntyanov
Okay, I also need to check the following points with you to help me determine the approximate location of the fault:
1. Connect to USB-C alone and you can boot normally
2. After disconnecting the USBC, connect the battery and press the PWR button for 1 second, but the computer cannot be turned on.
3. After plugging in the battery and then plugging in the USBC, the phone can be turned on. After turning on the phone, disconnect the USBC. Will it continue to be turned on?

nmuntyanov, 2024-01-16:
@lewisxhe
1 It boots normally
2 Yes, computer cannot be turned on
3 No, it powered off once I disconnected USBC

lewisxhe, 2024-01-17:
@nmuntyanov
Please connect the battery, disconnect the USB, and measure whether there is voltage at these two points.
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

lewisxhe, 2024-01-17:
If no voltage is measured, please short-circuit these two points. Please note that short-circuiting these two points means there is no reverse polarity protection. Please confirm the battery polarity.
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

lewisxhe, 2024-01-17:
If it uses USB power supply, can it be shut down by long pressing PWR?

nmuntyanov, 2024-01-17:
Yes, it can

lewisxhe, 2024-01-17:
1. When using USBC for power supply, you can use the PWR button to shut down. This indicates that the connection between the button and the PMU is normal, and the button circuit fault is eliminated.
2. If there is battery voltage at both ends of the measurement capacitor, it means that the battery voltage has reached the PMU input terminal.

After the above diagnosis, I judged that the internal power switching path of the PMU was damaged. This is a situation I have never encountered before. The only solution is to replace the PMU.

If it is still within the warranty period, please contact the salesperson for a replacement.

nmuntyanov, 2024-01-17:
Thank you for support. Will contact the seller

nmuntyanov, 2025-03-23:
@lewisxhe
Hello once agin
I've tried to replace PMU with new one and there was no effect.

I've have studied battery circuit and your recommendations once again and found that Q3 is not working.
Can you tell me with what I can replace it? Can't find it's name in schema.

lewisxhe, 2025-03-24:
N-channel MOSFET, using AO3400, you can also use other 3400 to replace

nmuntyanov, 2025-04-08:
Thank you, it works

Closed 2024-03-03.

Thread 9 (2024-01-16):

Following build instructions aren't working for Visual Studio Code

jasonthenderson, 2024-01-16:
I followed the Visual Studio Code build instructions exactly and am getting this error - any ideas?

Processing uhf_band (platform: espressif32; framework: arduino; board: esp32s3box)
--------------------------------------------------------------------------------------
UnknownBoard: Unknown board ID 'esp32s3box'

 *  The terminal process "C:\Users\jason\.platformio\penv\Scripts\platformio.exe 'run'" terminated with exit code: 1.
 *  Terminal will be reused by tasks, press any key to close it.

 *  Executing task: C:\Users\username\.platformio\penv\Scripts\platformio.exe run

Processing uhf_band (platform: espressif32; framework: arduino; board: esp32s3box)
--------------------------------------------------------------------------------------
UnknownBoard: Unknown board ID 'esp32s3box'

 *  The terminal process "C:\Users\username\.platformio\penv\Scripts\platformio.exe 'run'" terminated with exit code: 1.
 *  Terminal will be reused by tasks, press any key to close it.

lewisxhe, 2024-01-16:
The location of esp32s3box is located in the platformio boards directory. If it cannot be found, your platformio installation may not be completed.
https://github.com/platformio/platform-espressif32/blob/develop/boards/esp32s3box.json

Closed 2024-03-01.

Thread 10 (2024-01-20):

Getting an external microphone to work

jasonthenderson, 2024-01-20:
Do I actually need to remove the built-in microphone to get the external microphone to work, or could I just put some tape over the built-in microphone to prevent sound from getting to it?

If I do need to remove the built-in microphone are there any tips on how to best do this?  Do I heat it up with a soldering iron and try to remove with tweezers?  I understand it is 'do at your own risk' but was wondering if anyone had tried this and had any tips?

lewisxhe, 2024-01-24:
If you want to use an external microphone, you need to remove the microphone from the TWR board to work properly. Two microphones connected in parallel may also work, but the bias voltage may be incorrect.

You can only use a heat gun to remove the TWR microphone, not a soldering iron.

Closed 2024-03-08.

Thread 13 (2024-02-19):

Wifi not working after reflash with factory firmware

DL1DRK, 2024-02-19:
Dear all,

after a reflash to factory firmware the Wifi is no longer working. Tried to flash again the APRS-firmware, Display shows Wifi on, but will not connect to an existing network or will not provide an accesspoint.

Any clue? Any help?

lyusupov, 2024-02-19:
https://github.com/nakhonthai/ESP32APRS_T-TWR/discussions

Closed 2024-04-04.

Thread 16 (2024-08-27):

T TWR Rev 2.1 WiFi Password for NiceRF Factory Firmware

WH3080, 2024-08-27:
Today I received the above referenced product. After putting the system, I scrolled through the menus and found a Wi-Fi menu. I did turn on the Wi-Fi. The Wi-Fi is picked up on my smart phone however I could not find the password to join the Wi-Fi created by the board, please provide the password to join the T TWR 2.1 built in WiFi. I want to emphasize that I did not install any third party software / firmware.

lyusupov, 2024-08-27:
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

WH3080, 2024-08-27:
Thank you! 🙏

lyusupov, 2024-08-27:
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

Closed 2024-09-01.

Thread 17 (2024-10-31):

Few Questions about Pins definitions and uses

richonguzman, 2024-10-31:
1) SA868_SQL (pin IO_02) what does it do? just to get notified when Radio Carrier is detected?

2) VLOD A3 / ALDO3 is enable or disabled on T-TWR Plus 2.1 make no difference in radio behavior.

or how is the process of AMP_MUTE, AUDIO_IN, RADIO_MUTE, RADIO_AUDIO_OUTPUT ???

3)  AUDIO_IN and AMP_MUTE how and what does it amplify? ESP32_Audio or MIC_Audio or Received_Radio_Audio?

4)
`

void checkPTTPressed() {

        if (digitalRead(BUTTON_PTT_PIN)) {
            digitalWrite(SA868_MIC_SEL, LOW);
            digitalWrite(SA868_PTT_PIN, HIGH);
        } else {
            digitalWrite(SA868_PTT_PIN, LOW);
        }
        delay(10);
}
`

makes PTT pin trigger the mic and transmit to over VHF Radio, but this:

`
void sendTone() {
        Serial.print("sending Packet: "); Serial.println(packet);

        digitalWrite(SA868_MIC_SEL, HIGH);
        digitalWrite(SA868_PTT_PIN, LOW);

        playTone(SA868_MIC);
        delay(1000);
        stopTone(SA868_MIC);
        digitalWrite(SA868_PTT_PIN, HIGH);
}
`

sends tone from ESP32 through Radio VHF.

do you see how digitalWrite(SA868_PTT_PIN, Value) work in oposite ways?

lewisxhe, 2024-11-01:
1. https://github.com/Xinyuan-LilyGO/T-TWR/blob/1b8b328bc869da74f30a916a0db5028c74d17a8f/README.md?plain=1#L16
2. https://github.com/Xinyuan-LilyGO/T-TWR/blob/1b8b328bc869da74f30a916a0db5028c74d17a8f/lib/LilyGo_TWR_Library/src/TWRClass.cpp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
https://github.com/Xinyuan-LilyGO/T-TWR/blob/1b8b328bc869da74f30a916a0db5028c74d17a8f/lib/LilyGo_TWR_Library/src/TWRClass.cpp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
3. https://github.com/Xinyuan-LilyGO/T-TWR/blob/1b8b328bc869da74f30a916a0db5028c74d17a8f/lib/LilyGo_TWR_Library/src/TWRClass.cpp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
4. https://github.com/Xinyuan-LilyGO/T-TWR/blob/1b8b328bc869da74f30a916a0db5028c74d17a8f/examples/Factory/Factory.ino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
[5. ](https://github.com/Xinyuan-LilyGO/T-TWR/blob/1b8b328bc869da74f30a916a0db5028c74d17a8f/lib/LilyGo_TWR_Library/src/sa868.cpp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)

Closed 2024-12-16.

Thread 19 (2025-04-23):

Factory example

thanhphucse, 2025-04-23:
Hi LiLyGO team,
I have a question, does the Factory example include the full walkie-talkie feature, is it the same as the .bin file in the firmware directory?

examples/
├── Factory                         # TWR Factory Application
├── GPS_Basic_Example               # GPS example
├── GPS_Full_Example                # GPS example
 ........

Thank you very much!

lewisxhe, 2025-04-23:
Same, the factory firmware is the Factory example

Closed 2025-05-24.

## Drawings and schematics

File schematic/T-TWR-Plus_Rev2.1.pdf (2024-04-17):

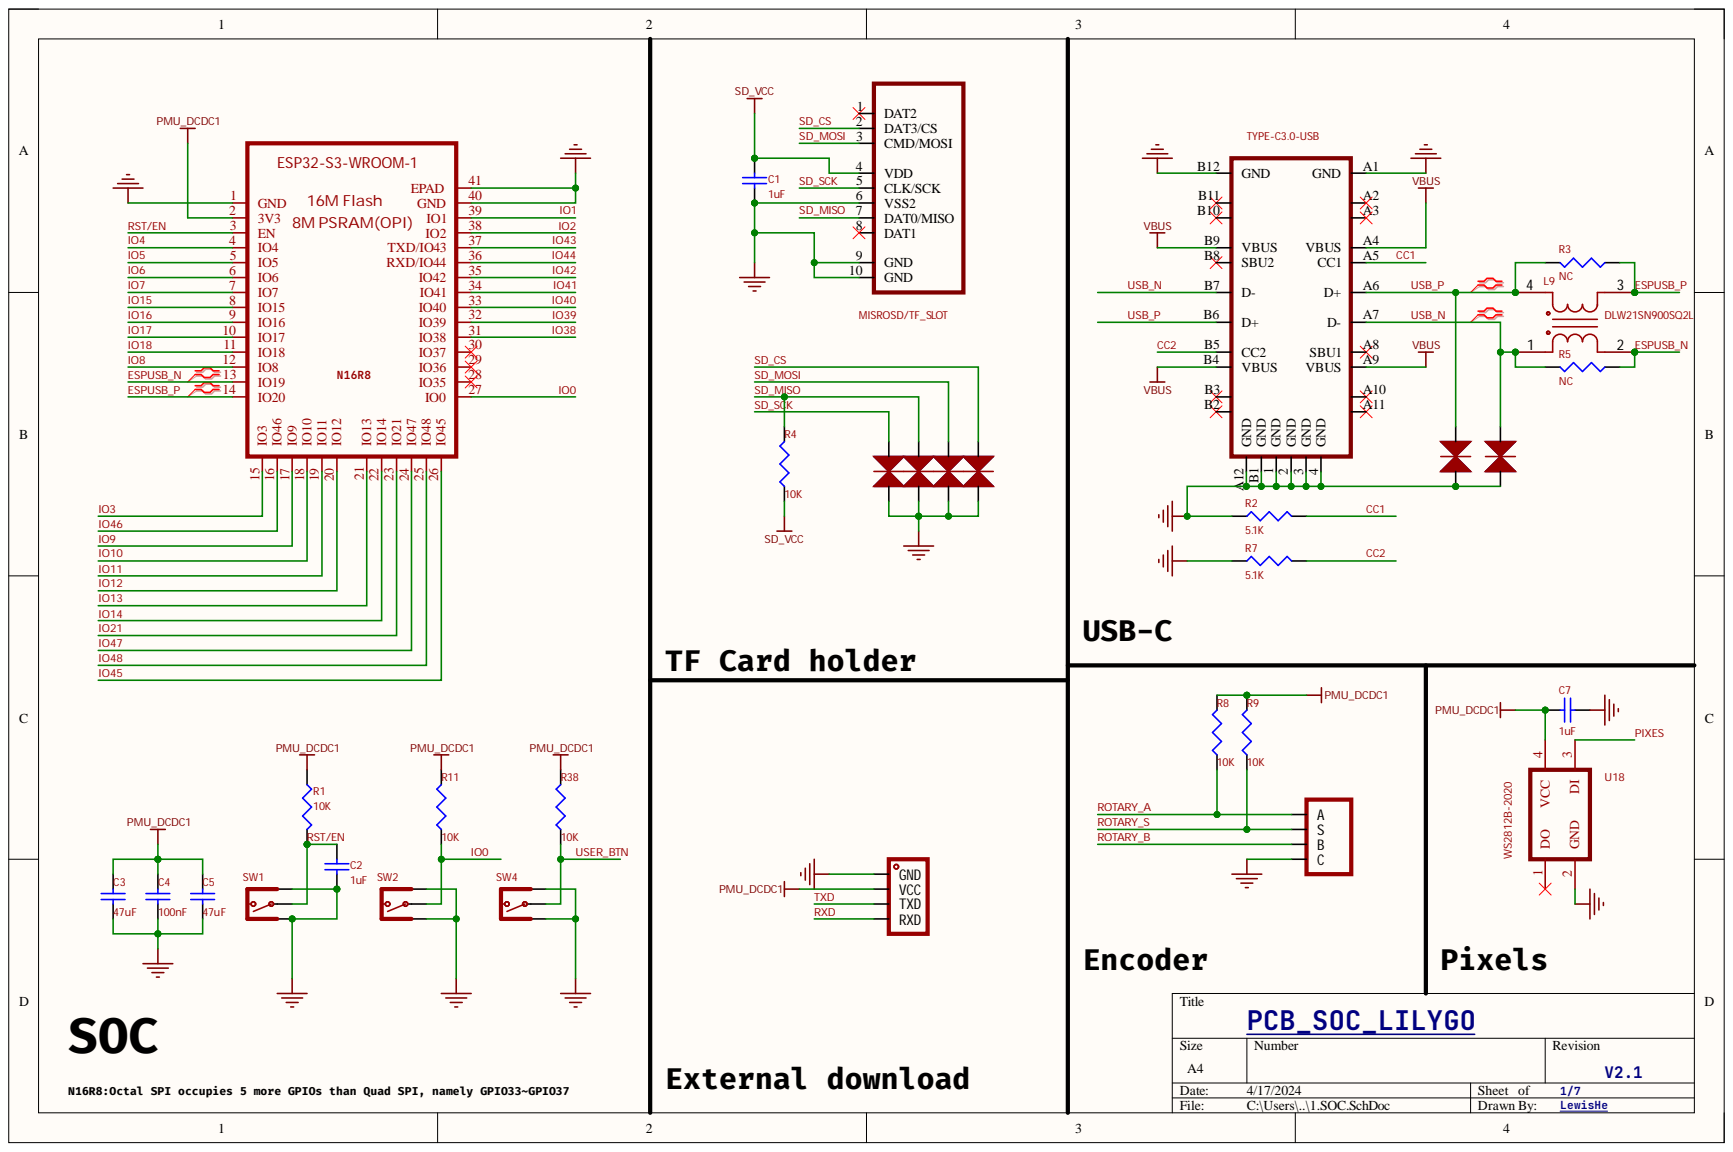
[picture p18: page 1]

Siz e A4 | Numb e r | R evisio n V2.1

N16R8:Octal SPI occupies 5 more GPIOs than Quad SPI, namely GPIO33~GPIO37

Da te : 4/17/202 4 | She et of 1 / 7
File : C:\Use rs\. .\1. SOC . S c hD o c | Dr awn B y : L e w i s H e (https://github.com/lewisxhe)

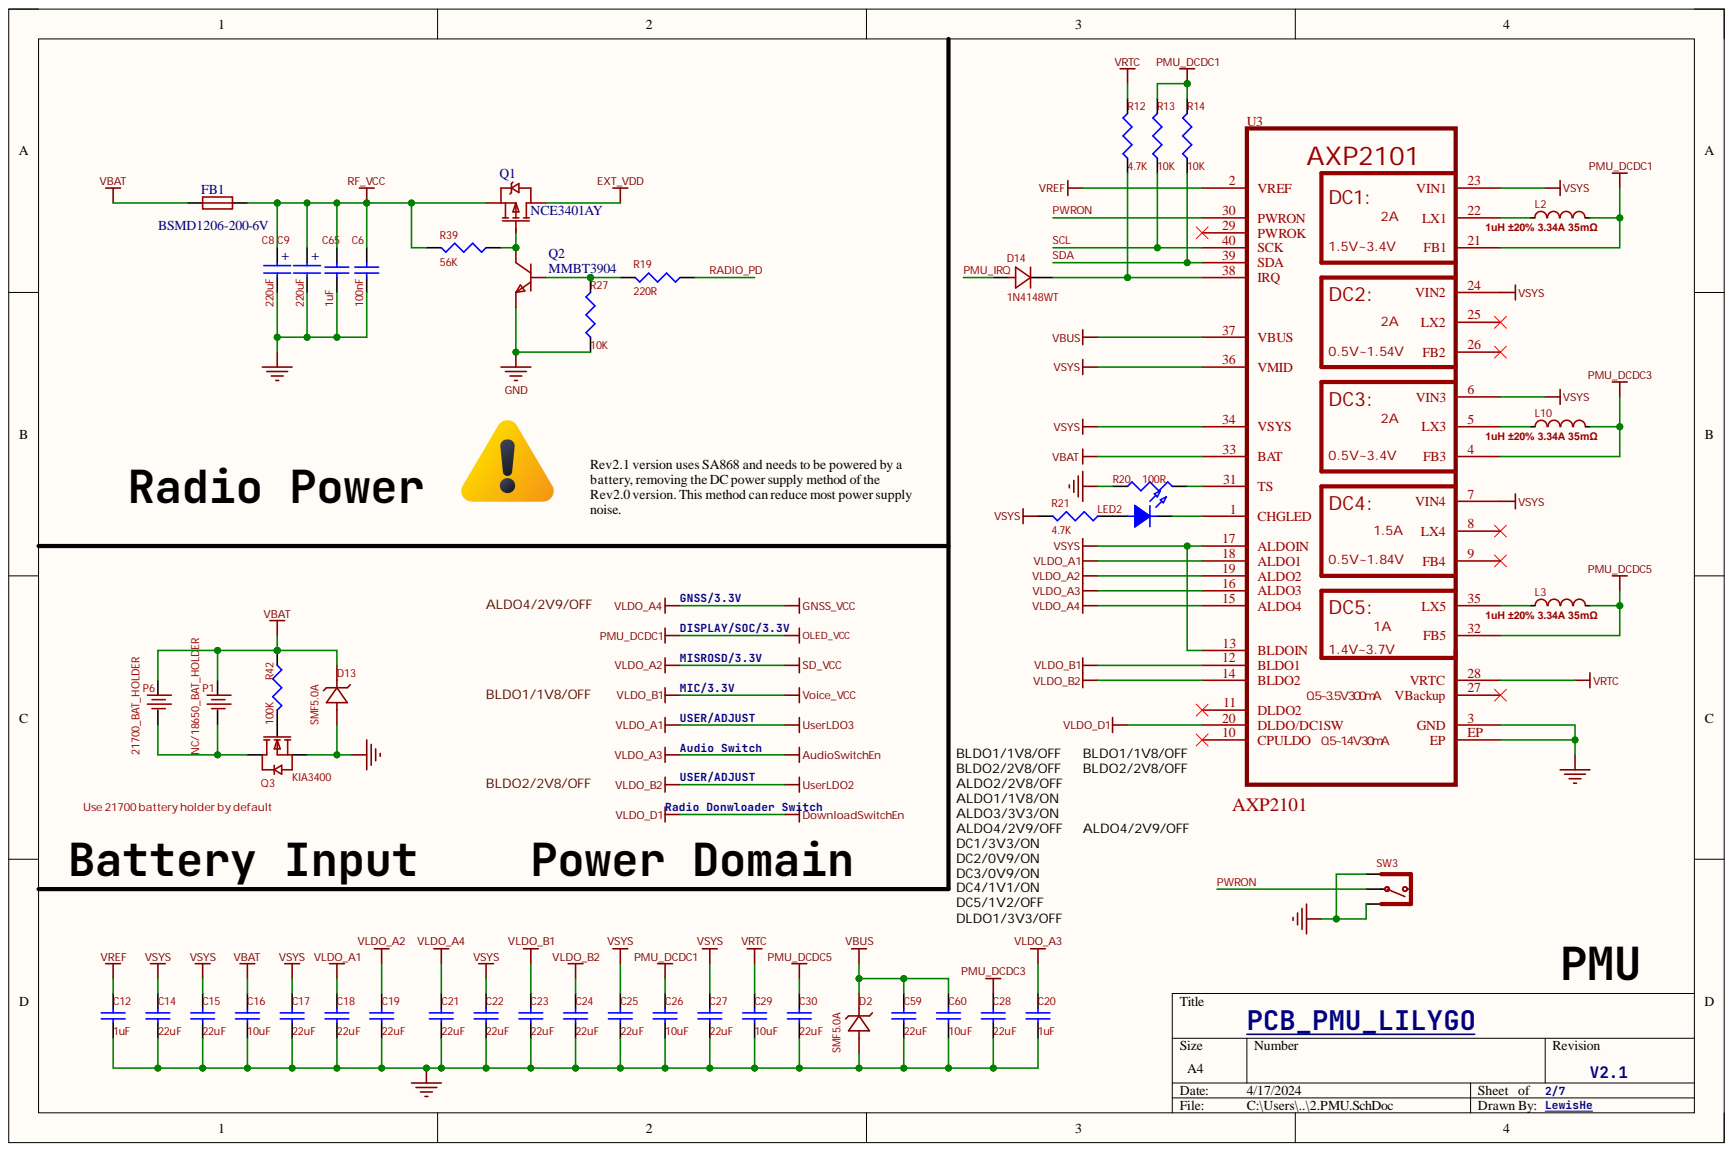
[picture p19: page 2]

Rev2.1 version uses SA868 and needs to be powered by a
battery, removing the DCpowersupply method ofthe
Rev2.0 version. This method can reduce most powersupply
noise.

Use 21700 battery holder by default
Battery Input

DownloadSwitchEn Radio Donwloader Switch

Size A4 | Number | Revision V2.1

Date: 4/17/2024 | Sheet of 2/7
File: C:\Users\..\2.PMU.SchDoc | Drawn By: LewisHe (https://github.com/lewisxhe)

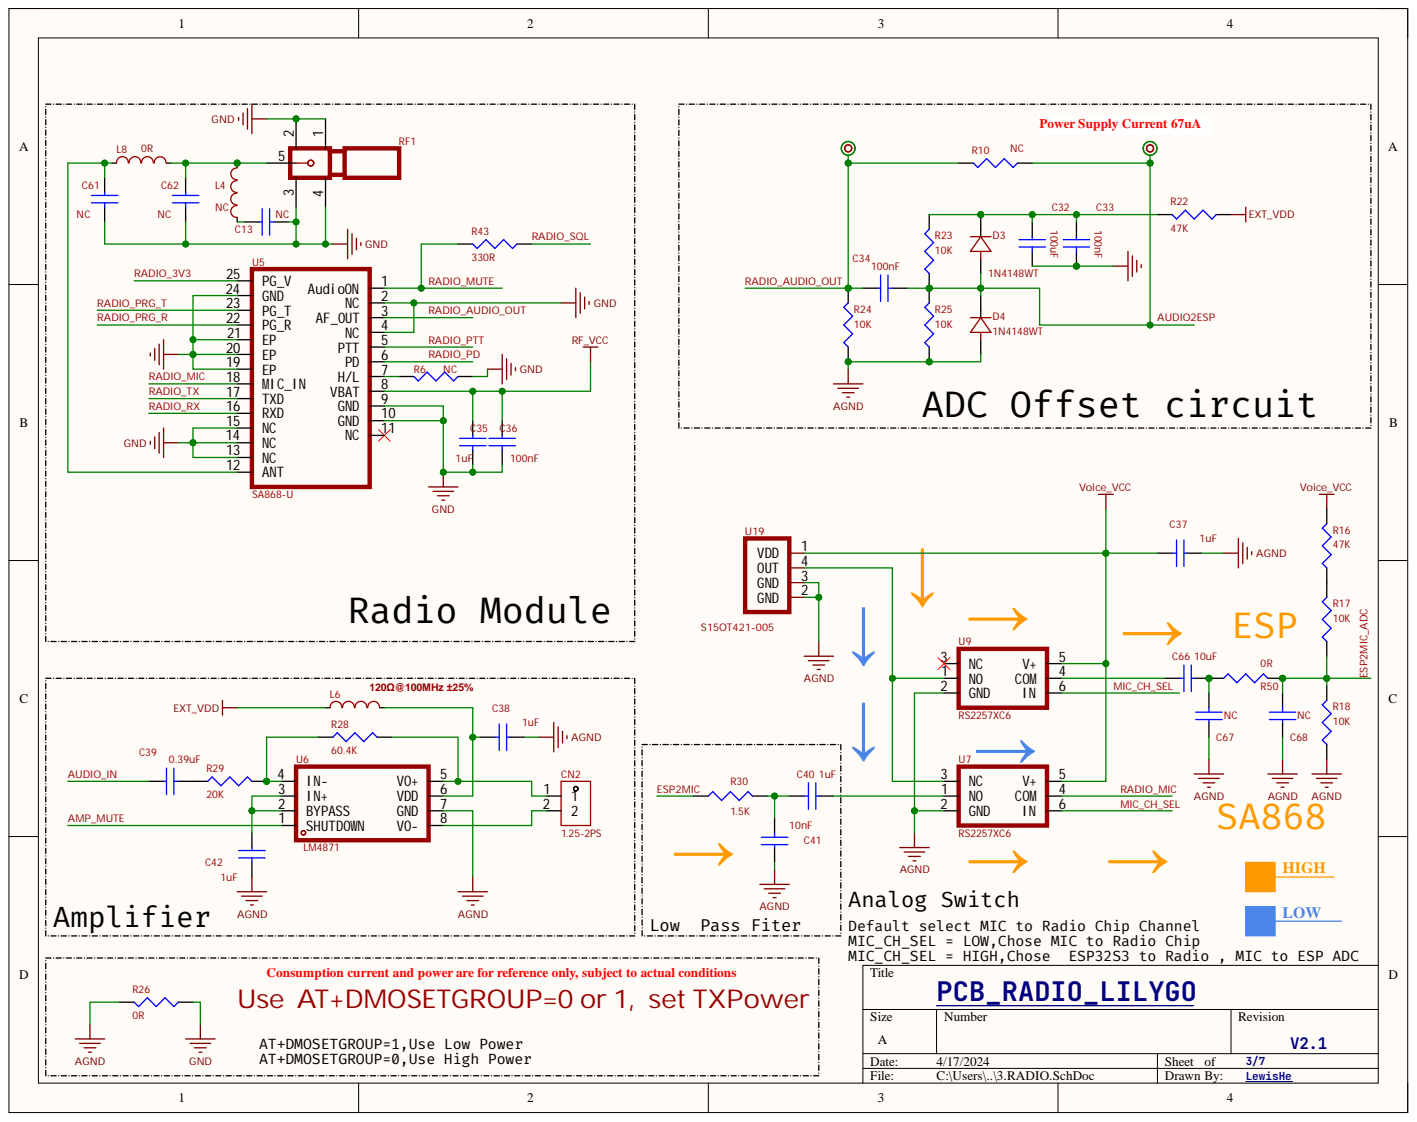
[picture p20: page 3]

AGND
Analog Switch
Default select MIC to Radio Chip Channel
MIC_CH_SEL = LOW,Chose MIC to Radio Chip
MIC_CH_SEL = HIGH,Chose ESP32S3 to Radio , MIC to ESP ADC
Title
PCB_RADIO_LILYGO (https://www.lilygo.cc)

Consumption current and power are for reference only, subject to actual conditions
Use AT+DMOSETGROUP=0 or 1, set TXPower

AT+DMOSETGROUP=1,Use Low Power
AT+DMOSETGROUP=0,Use High Power

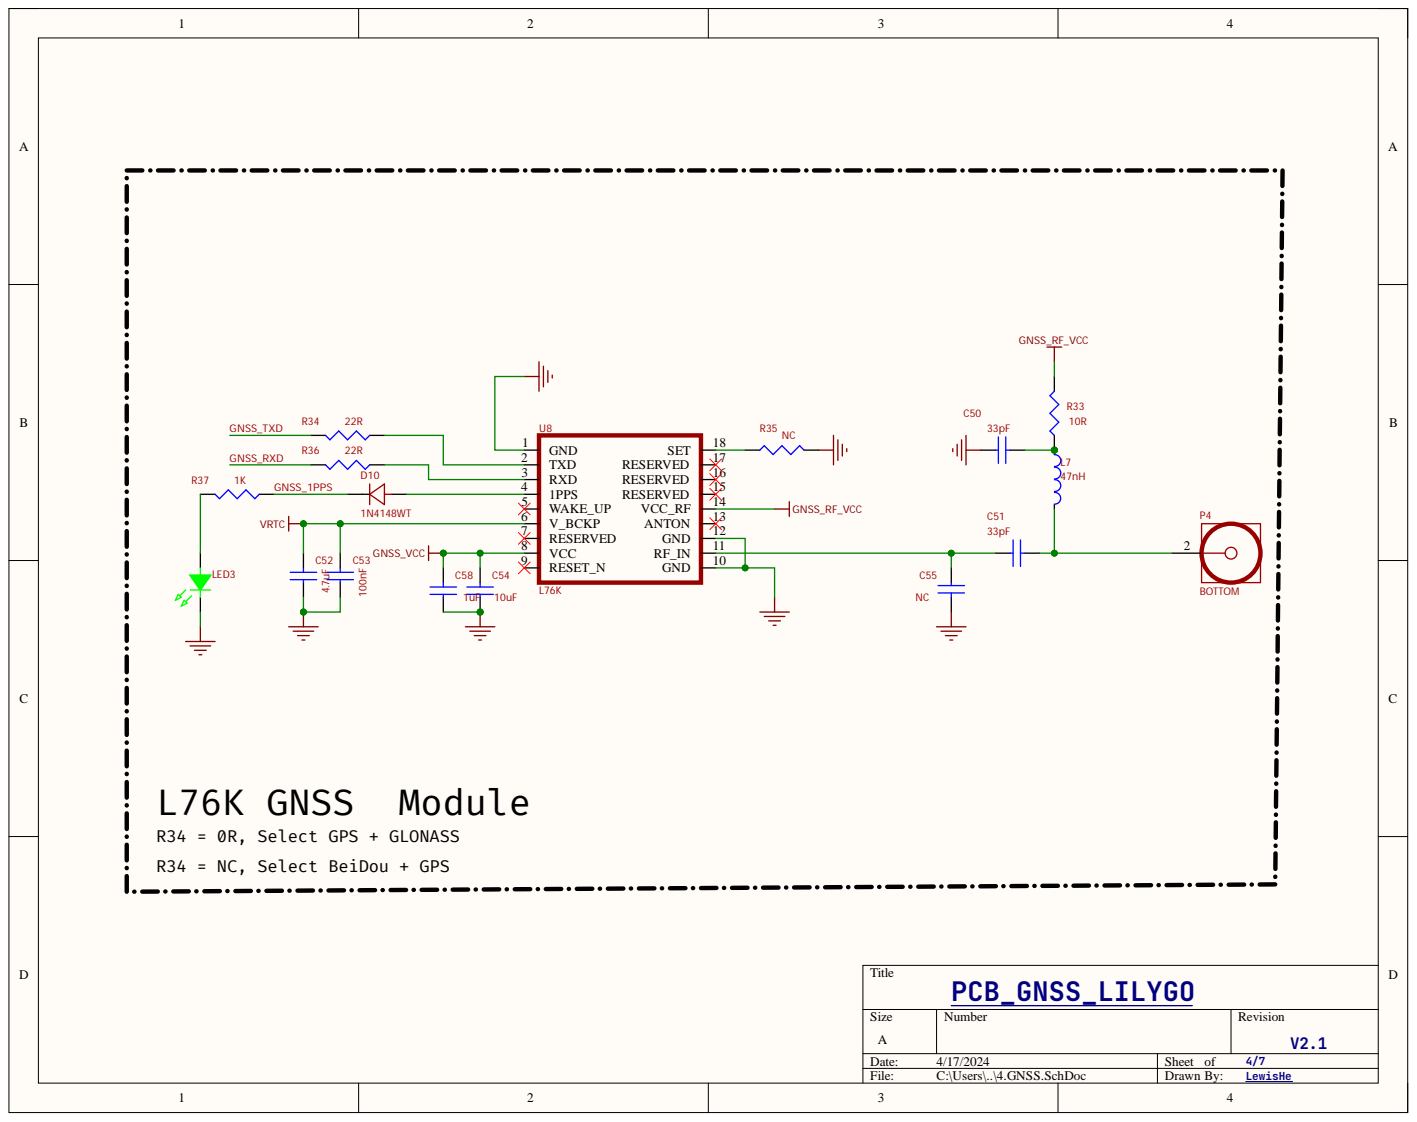
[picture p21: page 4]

R34 = NC, Select BeiDou + GPS GNSS_1PPS LED3

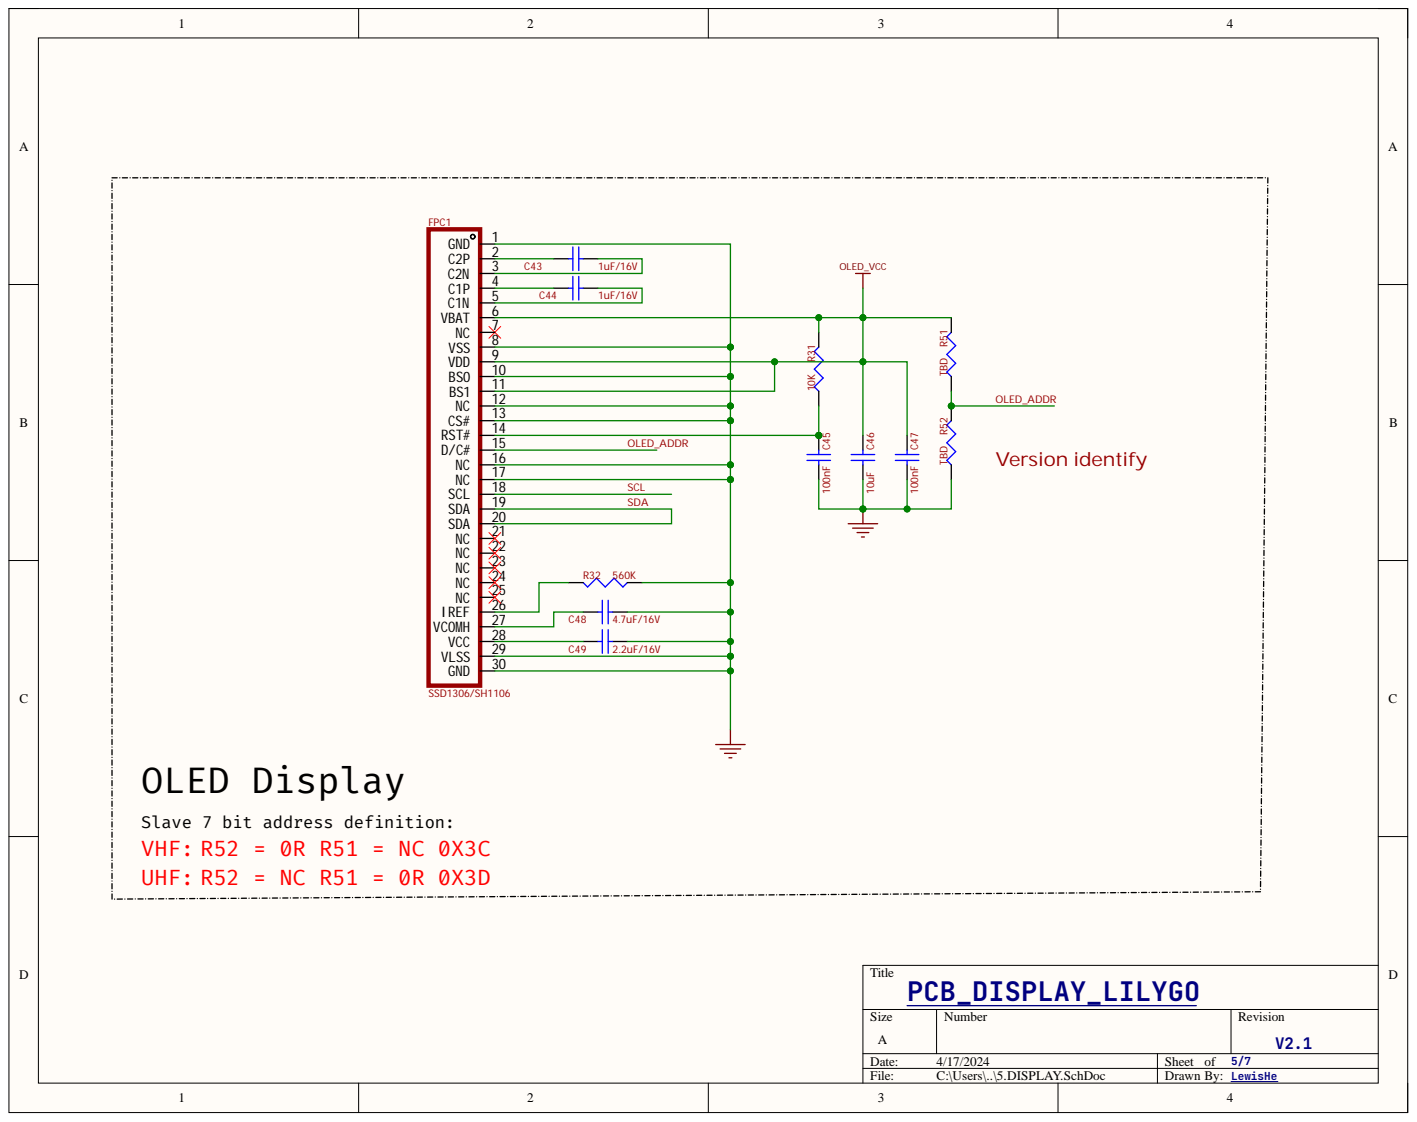
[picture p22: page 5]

3 C43 | 1uF/16V
5 C44 | 1uF/16V

1 0
1 1

1 3
1 4

Slave 7 bit address definition:

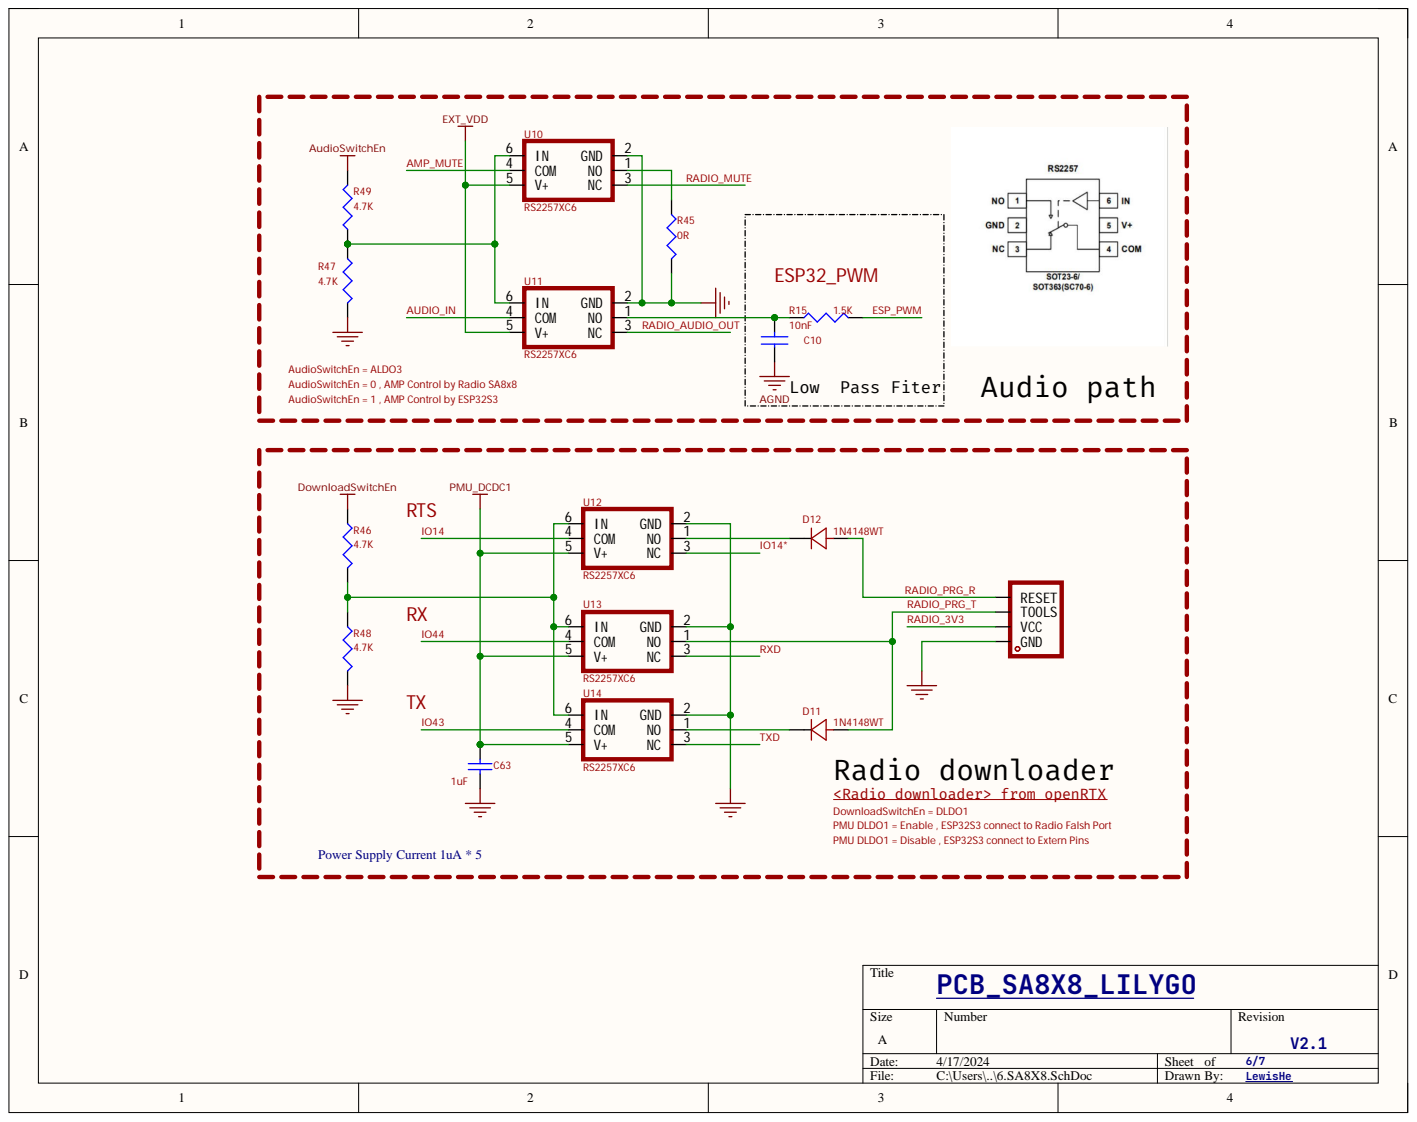
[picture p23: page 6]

3 2 | | RADIO_PR G_R

GND VCC TOOLS RESET

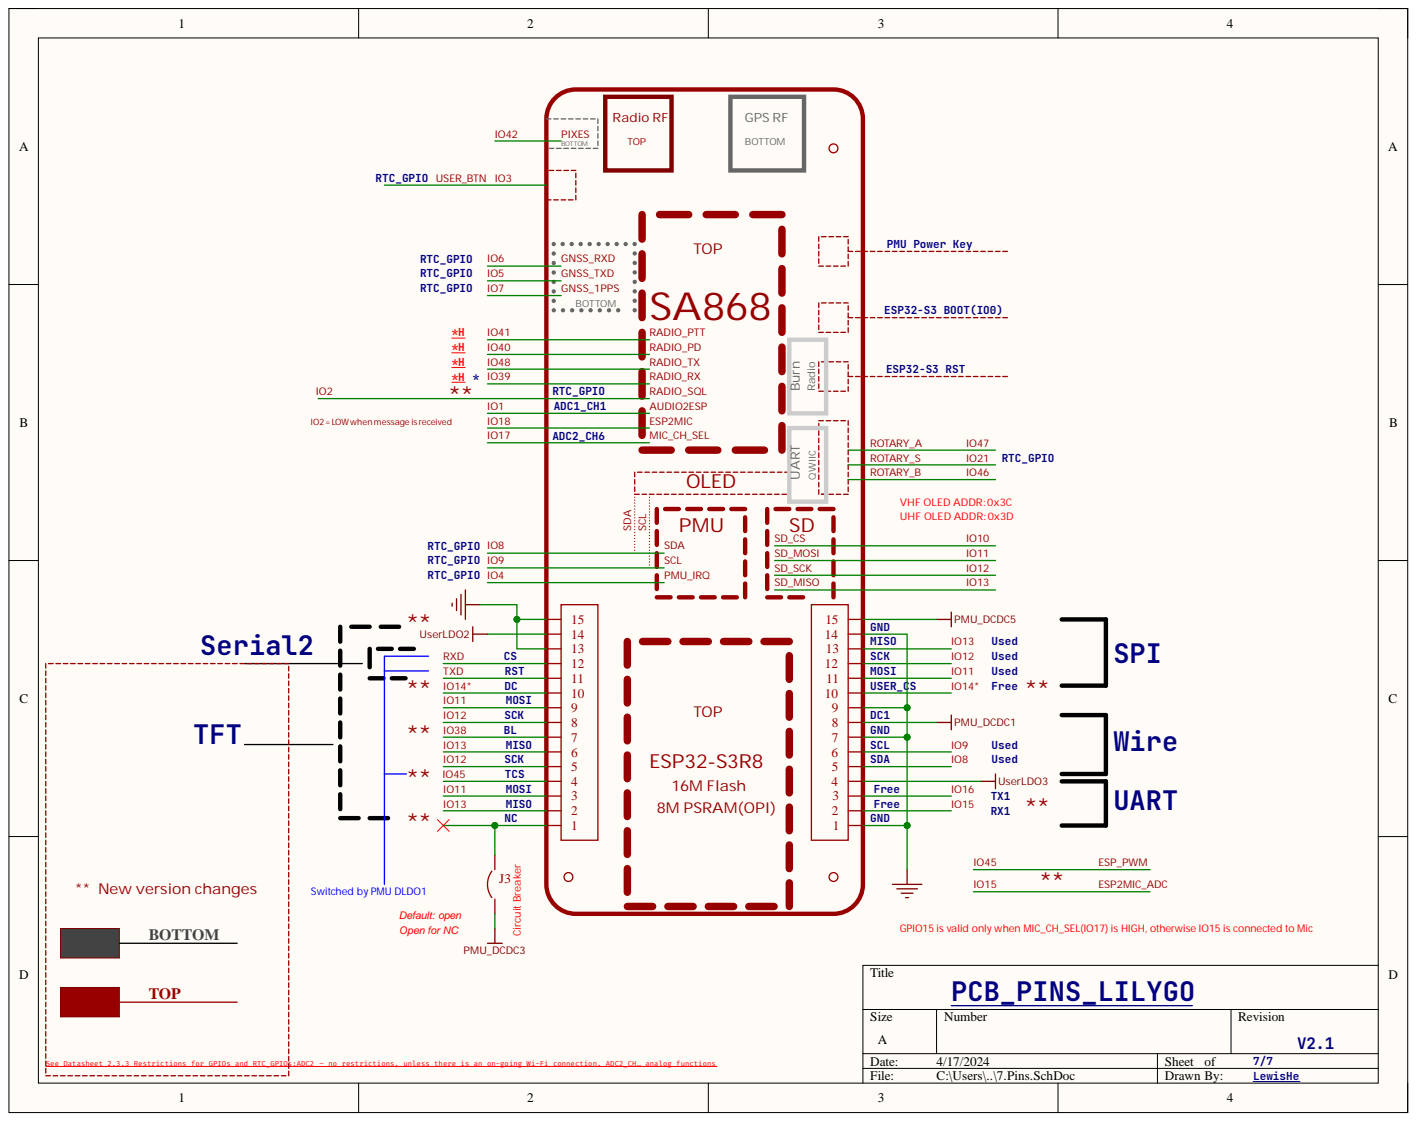
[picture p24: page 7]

IO2 = LOW when message is received

DC1
GND

GPIO15 is valid only when MIC_CH_SEL(IO17) is HIGH, otherwise IO15 is connected to Mic
PCB_PINS_LILYGO (https://www.lilygo.cc)

See Datasheet 2.3.3 Restrictions for GPIOs and RTC_GPIOs:ADC2 – no restrictions, unless there is an on-going Wi-Fi connection. ADC2_CH… analog functions (https://www.espressif.com.cn/sites/default/files/documentation/esp32-s3_datasheet_cn.pdf)

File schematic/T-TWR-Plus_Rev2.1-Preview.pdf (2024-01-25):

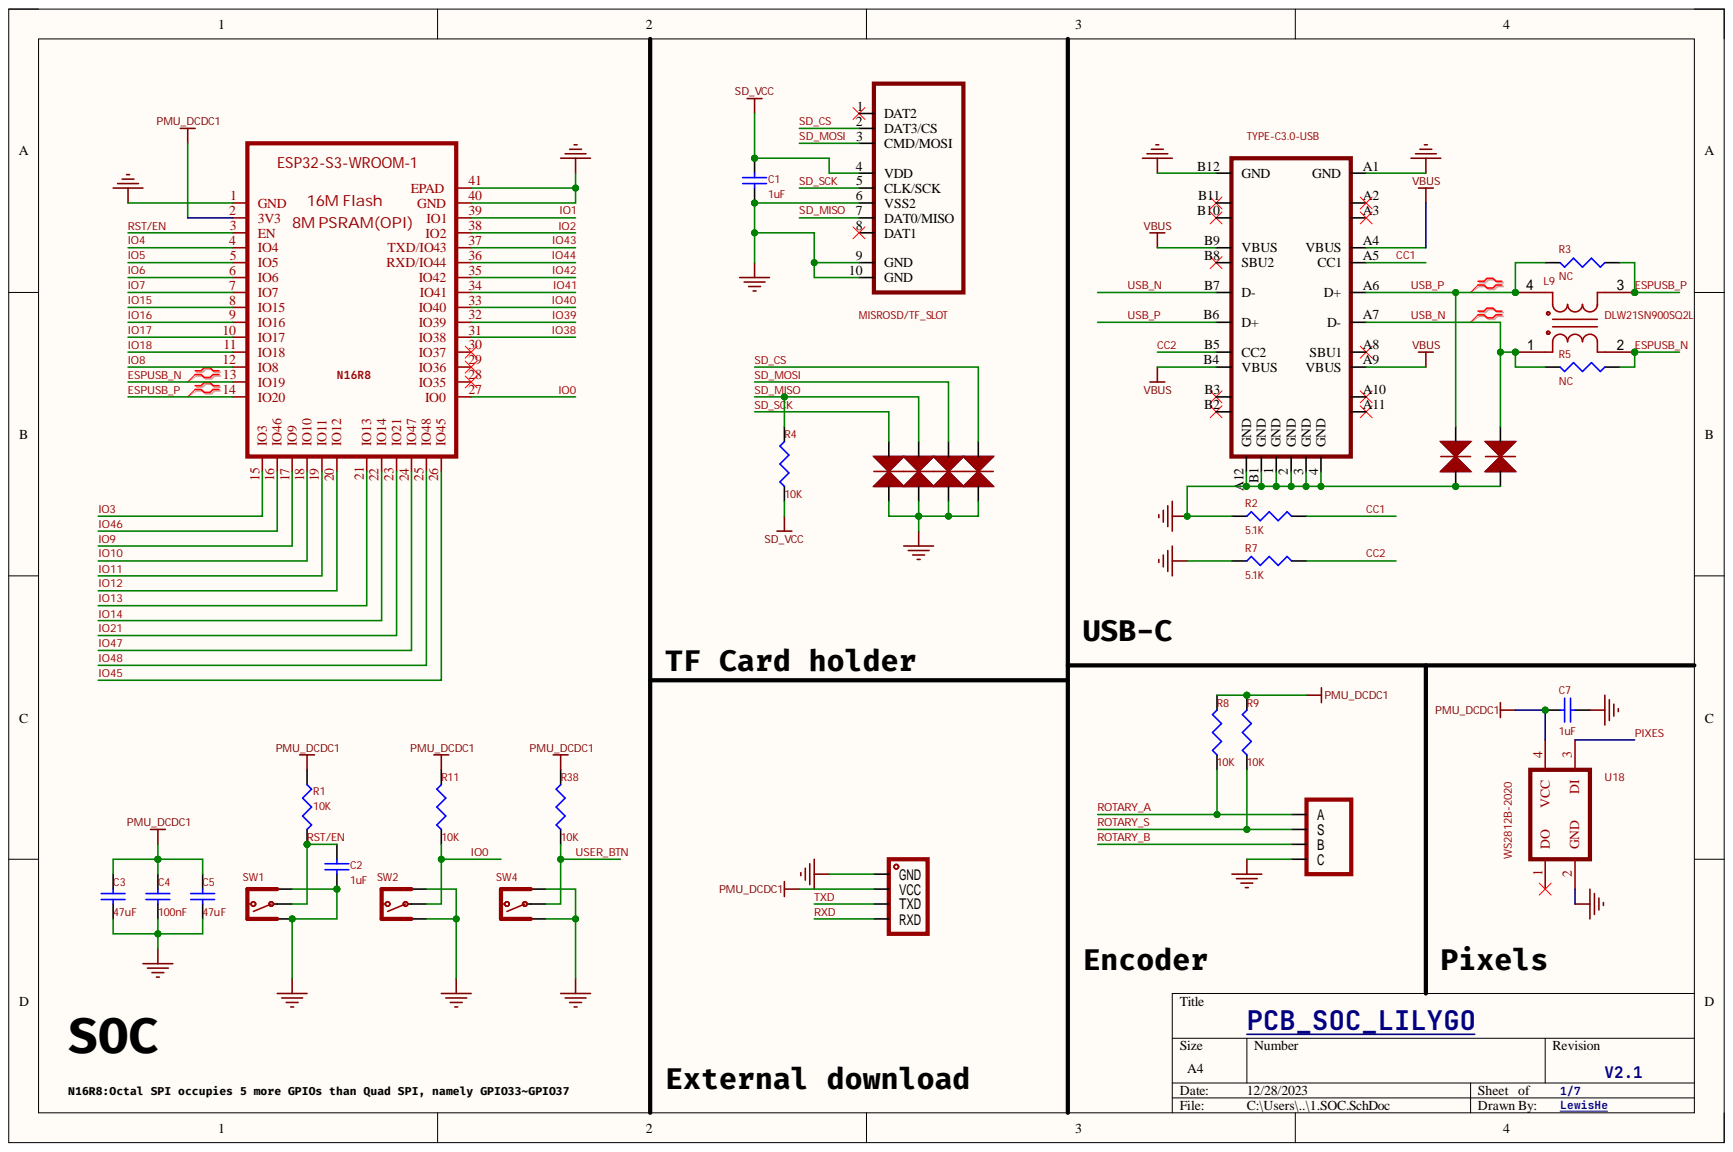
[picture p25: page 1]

Siz e A4 | Numb e r | R evisio n V2.1

N16R8:Octal SPI occupies 5 more GPIOs than Quad SPI, namely GPIO33~GPIO37

Da te : 12/28/20 2 3 | She et of 1 / 7
File : C:\Use rs\. .\1. SOC . S c hD o c | Dr awn B y : L e w i s H e (https://github.com/lewisxhe)

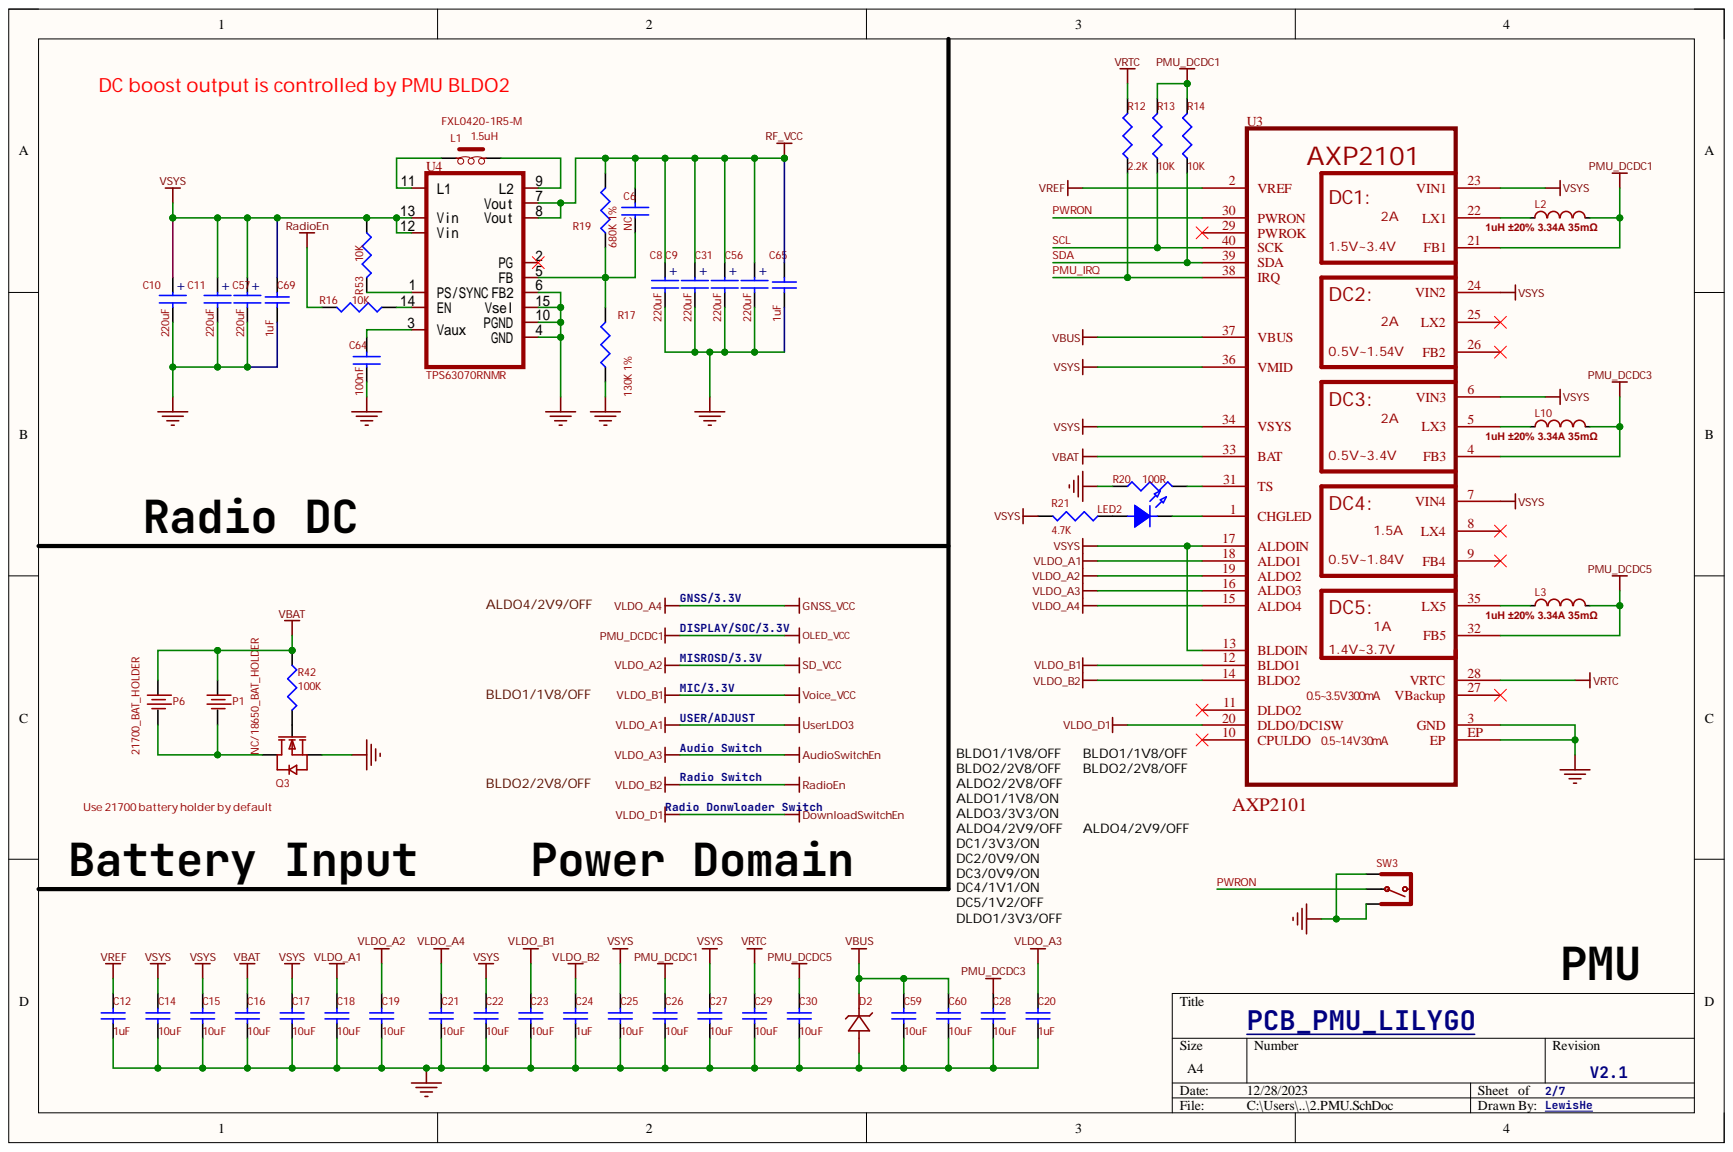
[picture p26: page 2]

DC boost output is controlled by PMU BLDO2

Use 21700 battery holder by default
Battery Input

DownloadSwitchEn Radio Donwloader Switch

Size A4 | Number | Revision V2.1

Date: 12/28/2023 | Sheet of 2/7
File: C:\Users\..\2.PMU.SchDoc | Drawn By: LewisHe (https://github.com/lewisxhe)

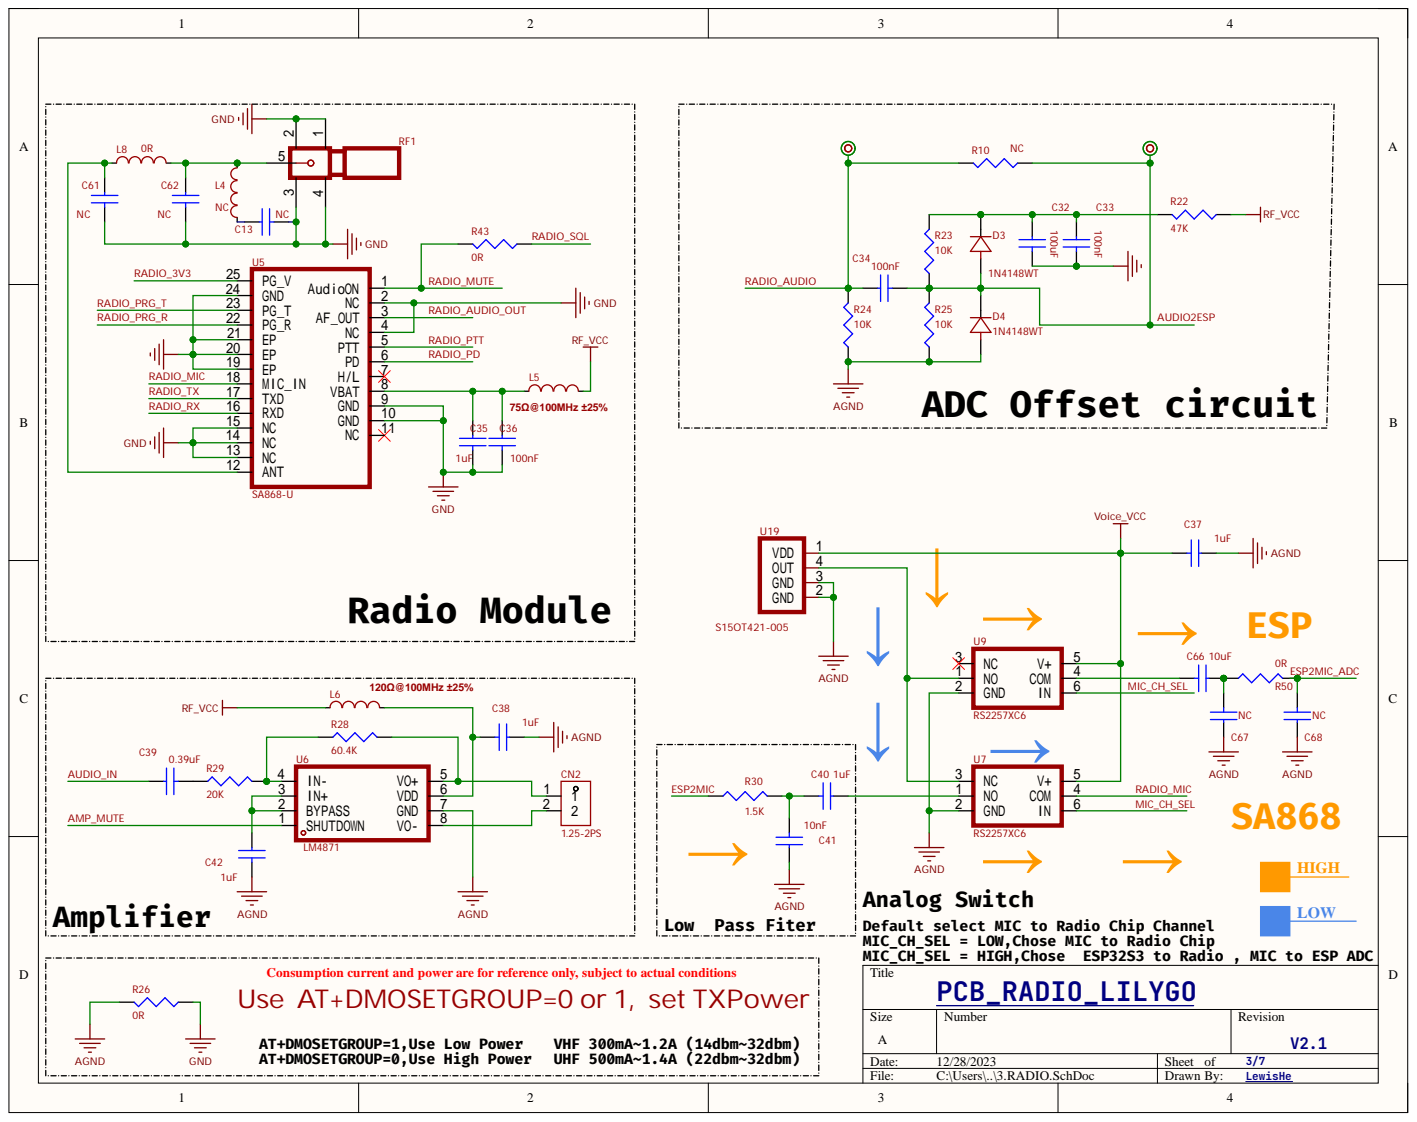
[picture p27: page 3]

AGND
Analog Switch
Default select MIC to Radio Chip Channel
MIC_CH_SEL = LOW,Chose MIC to Radio Chip
MIC_CH_SEL = HIGH,Chose ESP32S3 to Radio , MIC to ESP ADC
Title
PCB_RADIO_LILYGO (https://www.lilygo.cc)

Consumption current and power are for reference only, subject to actual conditions
Use AT+DMOSETGROUP=0 or 1, set TXPower

AT+DMOSETGROUP=1,Use Low Power
AT+DMOSETGROUP=0,Use High Power

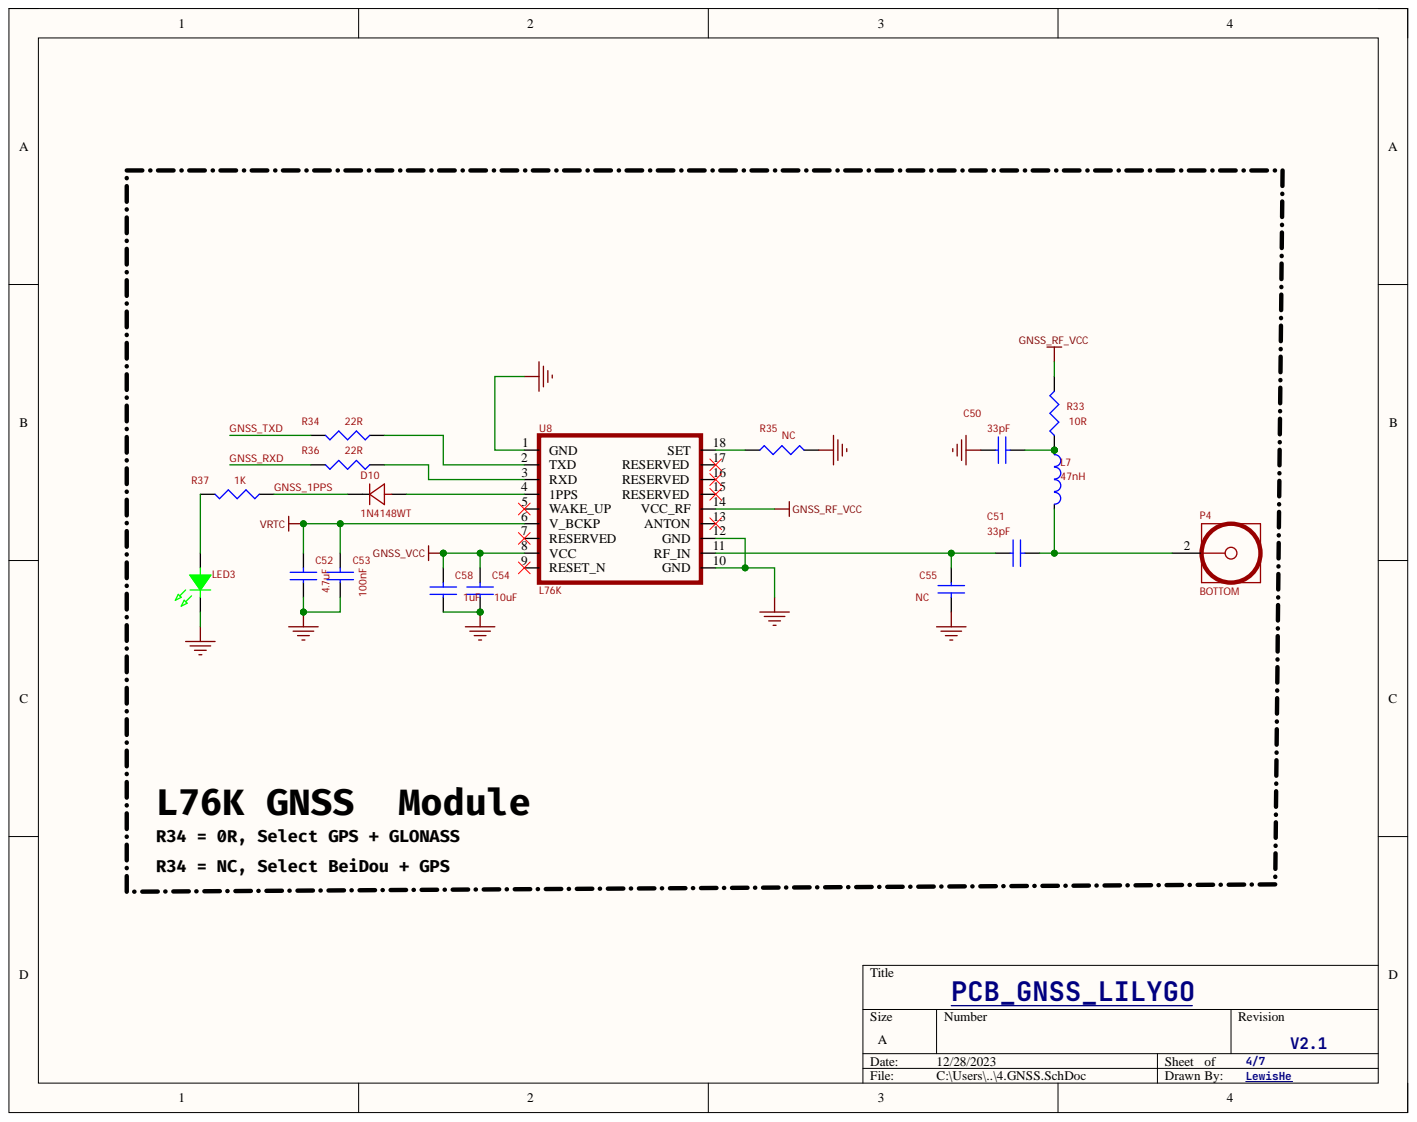
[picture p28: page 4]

R34 = NC, Select BeiDou + GPS GNSS_1PPS LED3

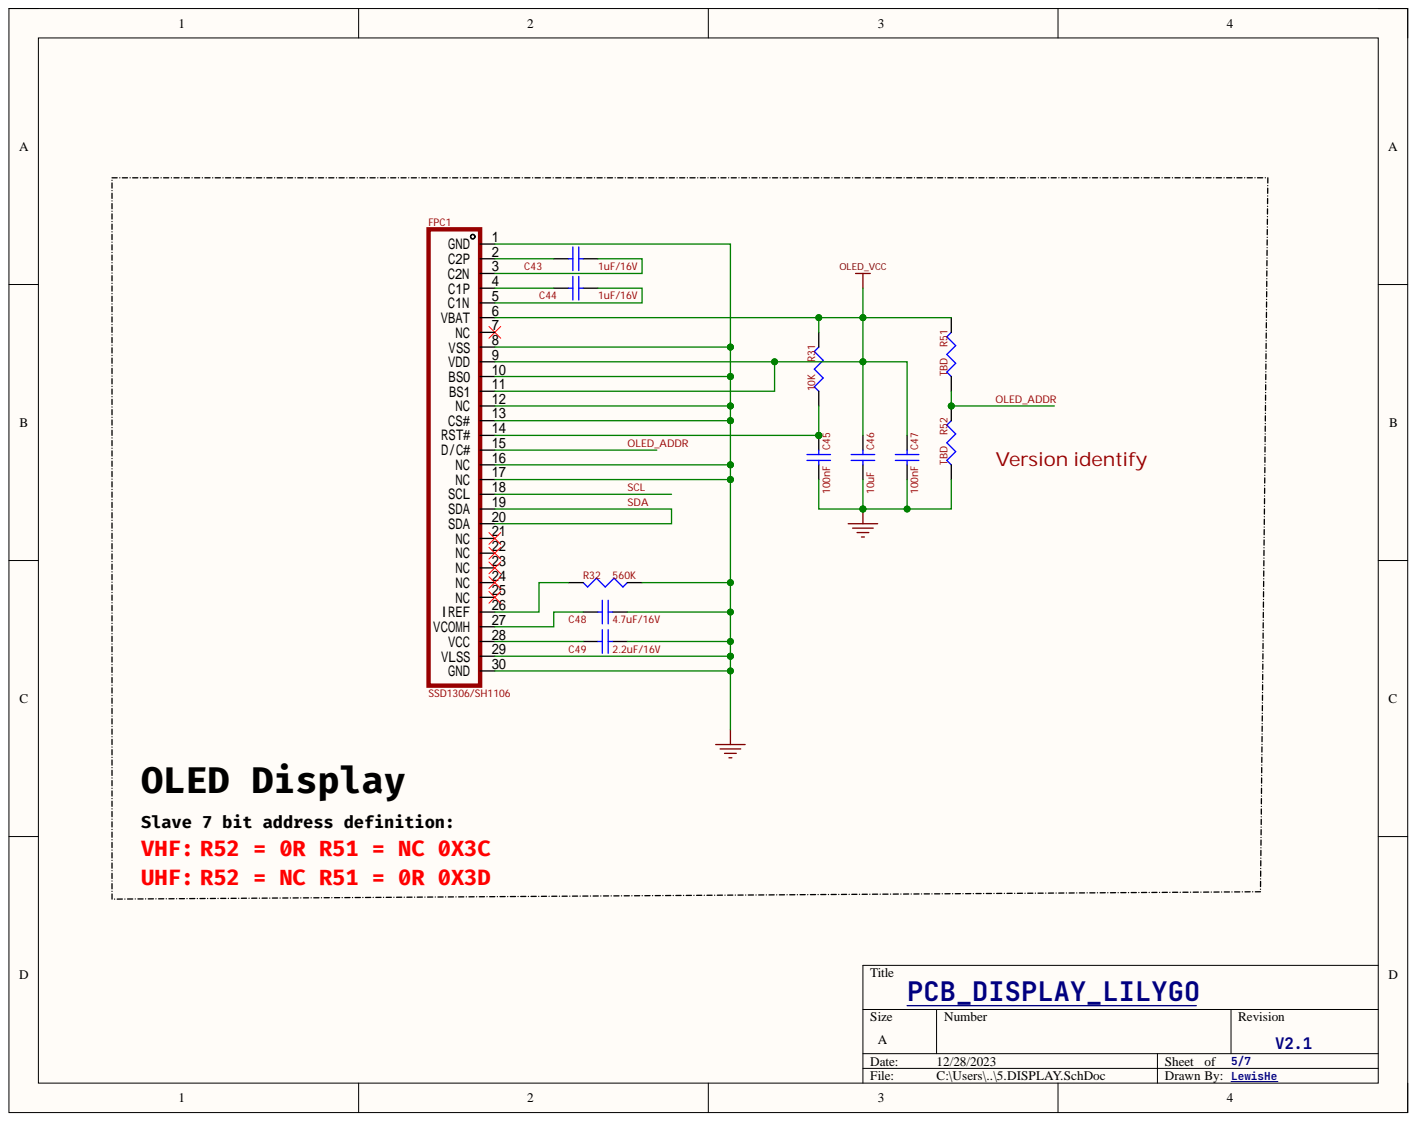
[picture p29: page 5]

Slave 7 bit address definition:



DC1
GND

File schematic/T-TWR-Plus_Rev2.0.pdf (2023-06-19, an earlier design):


IO45 26 IO0 27 IO35 28 IO36 29 IO37 30 IO38 31 IO39 32 IO40 33 IO41 34 IO42 35 RXD/IO44 36 TXD/IO43 37 IO2 38 IO1 39 GND 40 EPAD 41

SD_SCK

Size A4 | Number | Revision V1.0

N16R8:Octal SPI occupies 5 more GPIOs than Quad SPI, namely GPIO33~GPIO37

Date: 6/08/2023 | Sheet of 1/6
File: C:\Users\..\1.SOC.SchDoc | Drawn By: LewisHe


BAT 33 | | 1uH ±20% 3.34A35mΩ

TS 31 | PMU_DCDC5

ALDO2 19
ALDO4 15 ALDO3 16

BLDO1 12 BLDOIN 13


Consumption current and power are for reference only, subject to actual conditions

RADIO_PWR = LOW,Use Low Power
RADIO_PWR = HIGH,Use High Power

Mic: Standard operating voltage = 2V

AGND
Default select MIC to Radio Chip Channel
MIC_CH_SLE = LOW,Chose MIC to Radio Chip
MIC_CH_SLE = HIGH,Chose ESP32S3 to Radio




See Datasheet 2.3.3 Restrictions for GPIOs and RTC_GPIOs:ADC2 – no restrictions, unless there is an on-going Wi-Fi connection. ADC2_CH… analog functions (https://www.espressif.com.cn/sites/default/files/documentation/esp32-s3_datasheet_cn.pdf)

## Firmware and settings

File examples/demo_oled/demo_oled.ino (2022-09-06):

/******************************************************************************/
/***        include files                                                   ***/
/******************************************************************************/

#include "ui.h"
#include "data.h"
#include "sa868.h"

#include <U8g2lib.h>
#include <ArduinoJson.h>
#include <OneButton.h>
#include <Encoder.h>

#include <nvs.h>
#include <nvs_flash.h>

#include <Wire.h>
#include <LittleFS.h>
#include <Arduino.h>

/******************************************************************************/
/***        macro definitions                                               ***/
/******************************************************************************/

#define CONFIG_SA868_TX_PIN  (47)
#define CONFIG_SA868_RX_PIN  (48)
#define CONFIG_SA868_PTT_PIN (41)
#define CONFIG_SA868_PD_PIN  (40)
#define CONFIG_SA868_RF_PIN  (39)

#define CONFIG_BUTTON_PTT_PIN (38)
#define CONFIG_BUTTON_SW5_PIN (3)
#define CONFIG_BUTTON_SW6_PIN (4)

#define CONFIG_ENCODER_A_PIN   (9)
#define CONFIG_ENCODER_B_PIN   (5)
#define CONFIG_ENCODER_SW1_PIN (6)
#define CONFIG_ENCODER_SW2_PIN (7)
#define CONFIG_ENCODER_COM_PIN (8)

#define CONFIG_BATTERY_ADC_PIN (15)

#define CONFIG_LED_GREEN       (1)

/******************************************************************************/
/***        type definitions                                                ***/
/******************************************************************************/

typedef void (*EncoderCallback)(void *);

/******************************************************************************/
/***        local function prototypes                                       ***/
/******************************************************************************/

/******************************************************************************/
/***        exported variables                                              ***/
/******************************************************************************/

/******************************************************************************/
/***        local variables                                                 ***/
/******************************************************************************/

OneButton buttonUp(CONFIG_BUTTON_SW5_PIN, true);
OneButton buttonDown(CONFIG_BUTTON_SW6_PIN, true);
OneButton buttonOK(CONFIG_ENCODER_SW1_PIN, true);
Encoder encoder(CONFIG_ENCODER_B_PIN, CONFIG_ENCODER_A_PIN);

SA868 sa868(Serial1, CONFIG_SA868_PTT_PIN, CONFIG_SA868_PD_PIN, CONFIG_SA868_RF_PIN);
U8G2_SSD1306_128X64_NONAME_F_HW_I2C u8g2(U8G2_R1, U8X8_PIN_NONE, 14, 13);

EncoderCallback encoderFn;

/******************************************************************************/
/***        exported functions                                              ***/
/******************************************************************************/

void setup() {
    Serial.begin(115200);

    app_nvs_init();
    data_init(sa868);

    pinMode(21, OUTPUT);
    digitalWrite(21, HIGH);

    Serial1.begin(9600, SERIAL_8N1, CONFIG_SA868_RX_PIN, CONFIG_SA868_TX_PIN);
    sa868.begin();
    pinMode(CONFIG_BUTTON_PTT_PIN, INPUT);
    u8g2.begin();
    u8g2.clearBuffer();
    delay(1000);
    ui();
    buttonOKInit();
    buttonUp.attachClick(volumeUp);
    buttonDown.attachClick(volumeDown);
    buttonOK.attachClick(buttonOKClickCallbackMainPage);

    xTaskCreatePinnedToCore(buttonTask, "buttonTask", 4096, NULL, 4, NULL, ARDUINO_RUNNING_CORE);
    xTaskCreatePinnedToCore(encoderTask, "encoderTask", 2048, NULL, 4, NULL, 1);
    // xTaskCreatePinnedToCore(scanRFTask, "scanRFTask", 4096, NULL, 6, NULL, ARDUINO_RUNNING_CORE);
    xTaskCreatePinnedToCore(uiTask, "uiTask", 4096, NULL, 6, NULL, 1);
}


/******************************************************************************/
/***        local functions                                                 ***/
/******************************************************************************/

void app_nvs_init(void)
{
    //Initialize NVS
    esp_err_t ret = nvs_flash_init();
    if (ret == ESP_ERR_NVS_NO_FREE_PAGES || ret == ESP_ERR_NVS_NEW_VERSION_FOUND)
    {
        ESP_ERROR_CHECK(nvs_flash_erase());
        ret = nvs_flash_init();
    }
    ESP_ERROR_CHECK(ret);
}

#if 0
void scanRFTask(void *pvParameters) {
    double freq = 134.0;
    bool ret = false;
    while (1) {
        if (freq == 174.0)
            freq = 400.0;
        if (freq > 480.0)
            break;
        ret = sa868.scanRF(freq);
        if (ret)
            printf("scan freq: %lf, res: %s\n", freq, "Yes");
        freq += 0.125;
        delay(100);
    }
    vTaskDelete(NULL);
}
#endif

void uiTask(void *pvParameter) {
    while (1) {
        // u8g2.sendBuffer();
        data_save(sa868);
        delay(1000);
    }
    vTaskDelete(NULL);
}


uint8_t curPage = 0;
int8_t curCursor = 0;

void loop() {
    if (curPage == 0) {
        if (digitalRead(CONFIG_BUTTON_PTT_PIN)) {
            sa868.transmit();
            feedTransmitStatus(true);
        } else {
            sa868.receive();
            feedTransmitStatus(false);
        }
    }
    delay(10);
}


void buttonTask(void *pvParameters) {
    while (1) {
        buttonOK.tick();
        buttonUp.tick();
        buttonDown.tick();
        delay(10);
    }
    vTaskDelete(NULL);
}


void encoderTask(void *pvParameters) {
    int pos = 0;
    while (1) {
        int newPos = encoder.read();
        if (pos != newPos) {
            Serial.printf("I [Main]: pos = %d\r\n", newPos);
            if (encoderFn) {
                if (newPos > pos) {
                    encoderFn((void *)1);
                } else {
                    encoderFn((void *)-1);
                }
            }
            pos = newPos;
        }
        delay(10);
    }
    vTaskDelete(NULL);
}


void ui() {
    feedRSSI(sa868.getRSSI());
    feedVolume(sa868.volume);
    feedElectricity(0.0);
    feedSettingsMenu(false);
    feedFilterMenu(false);
    u8g2.sendBuffer();
    encoderFn = EncoderCallbackMainPage;
}


void volumeUp() {
    sa868.setVolume(sa868.volume + 1);
    feedVolume(sa868.volume);
}


void volumeDown() {
    sa868.setVolume(sa868.volume - 1);
    feedVolume(sa868.volume);
}


void buttonOKInit() {
    pinMode(CONFIG_ENCODER_COM_PIN, OUTPUT);
    digitalWrite(CONFIG_ENCODER_COM_PIN, LOW);

    pinMode(CONFIG_ENCODER_SW1_PIN, INPUT_PULLUP);

    pinMode(CONFIG_ENCODER_SW2_PIN, OUTPUT);
    digitalWrite(CONFIG_ENCODER_COM_PIN, LOW);
}


// settings page
void buttonOKClickCallbackSettingsPage()
{
    if (curCursor == 0) {
        curPage = 3;
        feedSettingsPagebarBandWidthPage();
        feedSettingsPagebarBandWidthPageBar1(!sa868.bandwidth);
        feedSettingsPagebarBandWidthPageBar2(sa868.bandwidth);
        u8g2.sendBuffer();
        encoderFn = EncoderCallbackBandWidthPage;
        if (sa868.bandwidth)
        {
            curCursor = 1;
        } else {
            curCursor = 0;
        }
        buttonOK.attachClick(buttonOKClickCallbackBandwidthPage);
        buttonOK.attachDoubleClick(buttonOKDoubleClickCallbackSettingsPage);
    } else if (curCursor == 1) {
        curPage = 4;
        feedSettingsPagebarTransFreqPage();
        feedSettingsPagebarTransFreqPageCXCSSList1((long long)sa868.transFreq, sa868.bandwidth, 400.0, 480.0);
        long long t = (long long)sa868.transFreq;
        if (sa868.bandwidth) {
            feedSettingsPagebarTransFreqPageCXCSSList2(sa868.transFreq - t, 0.25);
        } else {
            feedSettingsPagebarTransFreqPageCXCSSList2(sa868.transFreq - t, 0.125);
        }
        u8g2.sendBuffer();
        encoderFn = EncoderCallbackTransFreqPage1;
        curCursor = (int)(sa868.transFreq - 400.0);
        buttonOK.attachClick(buttonOKClickCallbackTransFreqPage1);
        buttonOK.attachDoubleClick(buttonOKDoubleClickCallbackSettingsPage);
    } else if (curCursor == 2) {
        curPage = 5;
        feedSettingsPagebarRecvFreqPage();
        feedSettingsPagebarTransFreqPageCXCSSList1((long long)sa868.recvFreq, sa868.bandwidth, 400.0, 480.0);
        long long t = (long long)sa868.recvFreq;
        if (sa868.bandwidth) {
            feedSettingsPagebarTransFreqPageCXCSSList2(sa868.recvFreq - t, 0.25);
        } else {
            feedSettingsPagebarTransFreqPageCXCSSList2(sa868.recvFreq - t, 0.125);
        }
        u8g2.sendBuffer();
        encoderFn = EncoderCallbackTransFreqPage1;
        curCursor = (int)(sa868.recvFreq - 400.0);
        buttonOK.attachClick(buttonOKClickCallbackRecvFreqPage1);
        buttonOK.attachDoubleClick(buttonOKDoubleClickCallbackSettingsPage);
    } else if (curCursor == 3) {
        curPage = 6;
        Serial.printf("sa868.txCXCSS: %d\r\n", sa868.txCXCSS);
        encoderFn = EncoderCallbackTXCXCSSPage;
        curCursor = sa868.txCXCSS;
        feedSettingsPagebarTxCXCSSPage();
        feedSettingsPagebarCXCSSPageCXCSSList(sa868.txCXCSS, cxcss, 122);
        u8g2.sendBuffer();
        buttonOK.attachClick(buttonOKClickCallbackTXCXCSSPage);
        buttonOK.attachDoubleClick(buttonOKDoubleClickCallbackSettingsPage);
    } else if (curCursor == 4) {
        curPage = 7;
        Serial.printf("sa868.sq: %d\r\n", sa868.sq);
        encoderFn = EncoderCallbackSQPage;
        curCursor = sa868.sq;
        feedSettingsPagebarSQPage();
        feedSettingsPagebarSQPageSlider(sa868.sq);
        u8g2.sendBuffer();
        buttonOK.attachClick(buttonOKClickCallbackSQPage);
        buttonOK.attachDoubleClick(buttonOKDoubleClickCallbackSettingsPage);
    } else if (curCursor == 5) {
        curPage = 8;
        Serial.printf("sa868.rxCXCSS: %d\r\n", sa868.rxCXCSS);
        encoderFn = EncoderCallbackRXCXCSSPage;
        curCursor = sa868.rxCXCSS;
        feedSettingsPagebarRxCXCSSPage();
        feedSettingsPagebarCXCSSPageCXCSSList(sa868.rxCXCSS, cxcss, 122);
        u8g2.sendBuffer();
        buttonOK.attachClick(buttonOKClickCallbackRXCXCSSPage);
        buttonOK.attachDoubleClick(buttonOKDoubleClickCallbackSettingsPage);
    }
}


void EncoderCallbackSettingsPage(void *pvParameters) {
    static int pos = 0;

    pos = pos + (int)pvParameters;
    if (pos > 5) {
        pos = 0;
    } else if (pos < 0) {
        pos = 5;
    }
    curCursor = pos;

    switch (pos) {
        case 0:
            feedSettingsPagebarBandWidth(true);
            feedSettingsPagebarTransFreq(false);
            feedSettingsPagebarRecvFreq(false);
            feedSettingsPagebarTxCXCSS(false);
            feedSettingsPagebarSQ(false);
            feedSettingsPagebarRxCXCSS(false);
            break;

        case 1:
            feedSettingsPagebarBandWidth(false);
            feedSettingsPagebarTransFreq(true);
            feedSettingsPagebarRecvFreq(false);
            feedSettingsPagebarTxCXCSS(false);
            feedSettingsPagebarSQ(false);
            feedSettingsPagebarRxCXCSS(false);
            break;

        case 2:
            feedSettingsPagebarBandWidth(false);
            feedSettingsPagebarTransFreq(false);
            feedSettingsPagebarRecvFreq(true);
            feedSettingsPagebarTxCXCSS(false);
            feedSettingsPagebarSQ(false);
            feedSettingsPagebarRxCXCSS(false);
            break;

        case 3:
            feedSettingsPagebarBandWidth(false);
            feedSettingsPagebarTransFreq(false);
            feedSettingsPagebarRecvFreq(false);
            feedSettingsPagebarTxCXCSS(true);
            feedSettingsPagebarSQ(false);
            feedSettingsPagebarRxCXCSS(false);
            break;

        case 4:
            feedSettingsPagebarBandWidth(false);
            feedSettingsPagebarTransFreq(false);
            feedSettingsPagebarRecvFreq(false);
            feedSettingsPagebarTxCXCSS(false);
            feedSettingsPagebarSQ(true);
            feedSettingsPagebarRxCXCSS(false);
            break;

        case 5:
            feedSettingsPagebarBandWidth(false);
            feedSettingsPagebarTransFreq(false);
            feedSettingsPagebarRecvFreq(false);
            feedSettingsPagebarTxCXCSS(false);
            feedSettingsPagebarSQ(false);
            feedSettingsPagebarRxCXCSS(true);
            break;

        default:
            break;
    }

    u8g2.sendBuffer();
}


void buttonOKDoubleClickCallbackSettingsPage()
{
    curPage = 1;
    encoderFn = EncoderCallbackSettingsPage;
    feedSettingsPage();
    buttonOK.attachClick(buttonOKClickCallbackSettingsPage);
    buttonOK.attachDoubleClick(buttonOKDoubleClickCallbackMainPage);
}


// bandwidth page
void buttonOKClickCallbackBandwidthPage()
{
    // todo: set bandwidth
    if (curCursor == 0) {
        sa868.bandwidth = false;
        // sa868.setGroup(false, sa868.transFreq, sa868.recvFreq, (teCXCSS)sa868.txCXCSS, sa868.sq, (teCXCSS)sa868.rxCXCSS);
    } else {
        sa868.bandwidth = true;
        // sa868.setGroup(true, sa868.transFreq, sa868.recvFreq, (teCXCSS)sa868.txCXCSS, sa868.sq, (teCXCSS)sa868.rxCXCSS);
    }
    // sa868.setGroup(sSA868Data.bandwidth, sSA868Data.transFreq, sSA868Data.recvFreq, (teCXCSS)sSA868Data.txCXCSS, sSA868Data.sq, (teCXCSS)sSA868Data.rxCXCSS);
    curPage = 1;
    encoderFn = EncoderCallbackSettingsPage;
    feedSettingsPage();
    buttonOK.attachClick(buttonOKClickCallbackSettingsPage);
    buttonOK.attachDoubleClick(buttonOKDoubleClickCallbackMainPage);
}


void EncoderCallbackBandWidthPage(void *pvParameters) {
    int pos = curCursor;

    pos = pos + (int)pvParameters;
    if (pos > 1) {
        pos = 0;
    } else if (pos < 0) {
        pos = 1;
    }
    curCursor = pos;
    switch (curCursor) {
        case 0:
            feedSettingsPagebarBandWidthPageBar1(true);
            feedSettingsPagebarBandWidthPageBar2(false);
            break;

        case 1:
            feedSettingsPagebarBandWidthPageBar1(false);
            feedSettingsPagebarBandWidthPageBar2(true);
            break;

        default:
            break;
    }
    u8g2.sendBuffer();
}

double tempFreq = 0.0;

// TransFreq Page
void buttonOKClickCallbackTransFreqPage1()
{
    encoderFn = EncoderCallbackTransFreqPage2;
    tempFreq = 400.0 + curCursor;
    long long t = (long long)sa868.transFreq;
    if (sa868.bandwidth) {
        curCursor = (sa868.transFreq - t) / 0.25;
    } else {
        curCursor = (sa868.transFreq - t) / 0.125;
    }
    buttonOK.attachClick(buttonOKClickCallbackTransFreqPage2);
}


void EncoderCallbackTransFreqPage1(void *pvParameters)
{
    int pos = curCursor;

    pos = pos + (int)pvParameters;
    if (pos > 79) {
        pos = 0;
    } else if (pos < 0) {
        pos = 79;
    }
    curCursor = pos;

    Serial.printf("curCursor: %d\r\n", curCursor);
    feedSettingsPagebarTransFreqPageCXCSSList1((long long)(400.0 + curCursor), sa868.bandwidth, 400.0, 480.0);
    u8g2.sendBuffer();
}


void buttonOKClickCallbackTransFreqPage2()
{
    // todo: set trans freq
    if (sa868.bandwidth) {
        tempFreq = tempFreq + curCursor * 0.25 ;
    } else {
        tempFreq = tempFreq + curCursor * 0.125 ;
    }
    sa868.setGroup(sa868.bandwidth, tempFreq, sa868.recvFreq, (teCXCSS)sa868.txCXCSS, sa868.sq, (teCXCSS)sa868.rxCXCSS);
    Serial.printf("I [Main]: set transFreq: %lf\r\n", sa868.transFreq);
    curPage = 1;
    encoderFn = EncoderCallbackSettingsPage;
    feedSettingsPage();
    buttonOK.attachClick(buttonOKClickCallbackSettingsPage);
    buttonOK.attachDoubleClick(buttonOKDoubleClickCallbackMainPage);
}


void EncoderCallbackTransFreqPage2(void *pvParameters)
{
    int pos = curCursor;
    int range = 0;
    pos = pos + (int)pvParameters;
    if (sa868.bandwidth) {
        range = (1 / 0.25) - 1;
    } else {
        range= (1 / 0.125) - 1;
    }
    if (pos > range) {
        pos = 0;
    } else if (pos < 0) {
        pos = range;
    }
    curCursor = pos;

    Serial.printf("curCursor: %d\r\n", curCursor);
    long long t = (long long)sa868.transFreq;
    if (sa868.bandwidth) {
        feedSettingsPagebarTransFreqPageCXCSSList2((curCursor * 0.25), 0.25);
    } else {
        feedSettingsPagebarTransFreqPageCXCSSList2((curCursor * 0.125), 0.125);
    }
    u8g2.sendBuffer();
}


// recv page
void buttonOKClickCallbackRecvFreqPage1()
{
    encoderFn = EncoderCallbackTransFreqPage2;
    tempFreq = 400.0 + curCursor;
    long long t = (long long)sa868.recvFreq;
    if (sa868.bandwidth) {
        curCursor = (sa868.recvFreq - t) / 0.25;
    } else {
        curCursor = (sa868.recvFreq - t) / 0.125;
    }
    buttonOK.attachClick(buttonOKClickCallbackRecvFreqPage2);
}


void buttonOKClickCallbackRecvFreqPage2()
{
    // todo: set recv freq
    if (sa868.bandwidth) {
        tempFreq = tempFreq + curCursor * 0.25 ;
    } else {
        tempFreq = tempFreq + curCursor * 0.125 ;
    }
    sa868.setGroup(sa868.bandwidth, sa868.transFreq, tempFreq, (teCXCSS)sa868.txCXCSS, sa868.sq, (teCXCSS)sa868.rxCXCSS);
    Serial.printf("I [Main]: set recvFreq: %lf\r\n", sa868.recvFreq);
    curPage = 1;
    encoderFn = EncoderCallbackSettingsPage;
    feedSettingsPage();
    buttonOK.attachClick(buttonOKClickCallbackSettingsPage);
    buttonOK.attachDoubleClick(buttonOKDoubleClickCallbackMainPage);
}


//TXCXCSS page
void buttonOKClickCallbackTXCXCSSPage()
{
    // todo: set TXCXCSS
    // sa868.txCXCSS = curCursor;
    sa868.setGroup(sa868.bandwidth, sa868.transFreq, sa868.recvFreq, (teCXCSS)curCursor, sa868.sq, (teCXCSS)sa868.rxCXCSS);
    curPage = 1;
    encoderFn = EncoderCallbackSettingsPage;
    feedSettingsPage();
    buttonOK.attachClick(buttonOKClickCallbackSettingsPage);
    buttonOK.attachDoubleClick(buttonOKDoubleClickCallbackMainPage);
}


void EncoderCallbackTXCXCSSPage(void *pvParameters)
{
    int pos = curCursor;

    pos = pos + (int)pvParameters;
    if (pos > 121) {
        pos = 0;
    } else if (pos < 0) {
        pos = 121;
    }
    curCursor = pos;

    feedSettingsPagebarTxCXCSSPage();
    feedSettingsPagebarCXCSSPageCXCSSList(curCursor, cxcss, 122);
    u8g2.sendBuffer();
}


// SQ page
void buttonOKClickCallbackSQPage()
{
    // todo: set SQ
    // sa868.sq = curCursor;
    sa868.setGroup(sa868.bandwidth, sa868.transFreq, sa868.recvFreq, (teCXCSS)sa868.txCXCSS, curCursor, (teCXCSS)sa868.rxCXCSS);
    curPage = 1;
    encoderFn = EncoderCallbackSettingsPage;
    feedSettingsPage();
    buttonOK.attachClick(buttonOKClickCallbackSettingsPage);
    buttonOK.attachDoubleClick(buttonOKDoubleClickCallbackMainPage);
}


void EncoderCallbackSQPage(void *pvParameters)
{
    int pos = curCursor;

    pos = pos + (int)pvParameters;
    if (pos > 8) {
        pos = 0;
    } else if (pos < 0) {
        pos = 8;
    }
    curCursor = pos;

    feedSettingsPagebarSQPage();
    feedSettingsPagebarSQPageSlider(pos);
    u8g2.sendBuffer();
}


//RXCXCSS page
void buttonOKClickCallbackRXCXCSSPage()
{
    // todo: set RXCXCSS
    // sa868.rxCXCSS = curCursor;
    sa868.setGroup(sa868.bandwidth, sa868.transFreq, sa868.recvFreq, (teCXCSS)sa868.txCXCSS, sa868.sq, (teCXCSS)curCursor);
    curPage = 1;
    encoderFn = EncoderCallbackSettingsPage;
    feedSettingsPage();
    buttonOK.attachClick(buttonOKClickCallbackSettingsPage);
    buttonOK.attachDoubleClick(buttonOKDoubleClickCallbackMainPage);
}


void EncoderCallbackRXCXCSSPage(void *pvParameters)
{
    int pos = curCursor;

    pos = pos + (int)pvParameters;
    if (pos > 121) {
        pos = 0;
    } else if (pos < 0) {
        pos = 121;
    }
    curCursor = pos;

    feedSettingsPagebarRxCXCSSPage();
    feedSettingsPagebarCXCSSPageCXCSSList(curCursor, cxcss, 122);
    u8g2.sendBuffer();
}


// filter page
void buttonOKClickCallbackFilterPage()
{
    if (curCursor == 0) {
        feedFilterPageBar1(true, !sa868.emphasis);
        // sa868.emphasis = !sa868.emphasis;
        sa868.setFilter(!sa868.emphasis, sa868.highPass, sa868.lowPass);
    } else if (curCursor == 1) {
        feedFilterPageBar2(true, !sa868.highPass);
        // sa868.highPass = !sa868.highPass;
        sa868.setFilter(sa868.emphasis, !sa868.highPass, sa868.lowPass);
    } else if (curCursor == 2) {
        feedFilterPageBar3(true, !sa868.lowPass);
        // sa868.lowPass = !sa868.lowPass;
        sa868.setFilter(sa868.emphasis, sa868.highPass, !sa868.lowPass);
    }
    u8g2.sendBuffer();
}


void EncoderCallbackFilterPage(void *pvParameters)
{
    static int pos = 0;

    pos = pos + (int)pvParameters;
    if (pos > 2) {
        pos = 0;
    } else if (pos < 0) {
        pos = 2;
    }
    curCursor = pos;
    switch (curCursor) {
        case 0:
            feedFilterPageBar1(true, sa868.emphasis);
            feedFilterPageBar2(false, sa868.highPass);
            feedFilterPageBar3(false, sa868.lowPass);
            break;

        case 1:
            feedFilterPageBar1(false, sa868.emphasis);
            feedFilterPageBar2(true, sa868.highPass);
            feedFilterPageBar3(false, sa868.lowPass);
            break;

        case 2:
            feedFilterPageBar1(false, sa868.emphasis);
            feedFilterPageBar2(false, sa868.highPass);
            feedFilterPageBar3(true, sa868.lowPass);
            break;

        default:
            break;
    }
    u8g2.sendBuffer();
}
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

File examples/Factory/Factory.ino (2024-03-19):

/**
 * @file      Factory.ino
 * @author    Lewis He (lewishe@outlook.com)
 * @license   MIT
 * @copyright Copyright (c) 2024  Shenzhen Xin Yuan Electronic Technology Co., Ltd
 * @date      2024-01-04
 * @note      Compatible with LilyGo TWR Rev2.0 and Rev2.1
 * * Currently, SA868 only supports NiceRF factory AT firmware and does not support OpenRTX firmware for the time being.
 * * Menu inspired by https://giltesa.com/2020/09/07/menu-grafico-para-pantalla-oled-en-arduino
 */

#include <U8g2lib.h>
#include <Rotary.h>
#include <TinyGPS++.h>
#include <WiFi.h>
#include <BLEServer.h>
#include <WiFiAP.h>
#include <SD.h>
#include "BLE.h"
#include "fix_fft.h"
#include <AceButton.h>
#include <Adafruit_NeoPixel.h>
#include <Adafruit_Sensor.h>
#include <Adafruit_BME280.h>
#include <ESPAsyncWebServer.h>
#include <ESPmDNS.h>
#include <ArduinoOTA.h>
#include <SPIFFS.h>
#include "Constants.h"
#include "WebIndex.h"


#define DEBUG_PORT Serial    // Output debugging information
#include "LilyGo_TWR.h"

using namespace ace_button;

enum Button {
    ShortPress,
    LongPress,
    Unknown
};

#define DECLARE_DEMO(function)      void function(uint8_t menuSelect)
#define U8G2_HOR_ALIGN_CENTER(t)    ((u8g2.getDisplayWidth() - (u8g2.getUTF8Width(t))) / 2)
#define U8G2_HOR_ALIGN_RIGHT(t)     (u8g2.getDisplayWidth()  -  u8g2.getUTF8Width(t))


DECLARE_DEMO(demoLed);
DECLARE_DEMO(demoSpeaker);
DECLARE_DEMO(demoOled);
DECLARE_DEMO(demoButton);
DECLARE_DEMO(demoMic);
DECLARE_DEMO(demoAlarm);
DECLARE_DEMO(demoSensor);
DECLARE_DEMO(demoGPS);
DECLARE_DEMO(demoSDCard);
DECLARE_DEMO(demoPMU);
DECLARE_DEMO(demoTransFreq);
DECLARE_DEMO(demoRecvFreq);
DECLARE_DEMO(demoSquelchLevel);
DECLARE_DEMO(demoPowerLevel);
DECLARE_DEMO(demoFilter);
DECLARE_DEMO(demoBLE);
DECLARE_DEMO(demoWiFi);
DECLARE_DEMO(demoSetting);
DECLARE_DEMO(demoDevInfo);
DECLARE_DEMO(drawError);


uint32_t readRotary(uint32_t cur, uint32_t minOut, uint32_t maxOut, uint32_t steps = 1 );
void printMain();
void printPowerOFF();
Button readButton();

struct demo_struct {
    const char      *demo_item;
    const char      *demo_description;
    const uint8_t   demo_icon[32];
    void            (*demo_func)(uint8_t menuSelect);
} demo [] = {
    //* {
    //*         Title,
    //*         Description,
    //*         XBM ICON,
    //*         Callback,
    //* },
    {
        "LED",
        "PIXELS RGB LED",
        { 0x00, 0x00, 0xe0, 0x01, 0xe0, 0x01, 0x60, 0x3f, 0x7f, 0x7f, 0x7f, 0xc1, 0x60, 0x81, 0x60, 0x8f, 0x60, 0x8f, 0x60, 0x81, 0x7f, 0xc1, 0x7f, 0x7f, 0x60, 0x3f, 0xe0, 0x01, 0xe0, 0x01, 0x00, 0x00 },
        demoLed
    },
    {
        "SPEAKER",
        "PLAYING GAME MELODIES",
        { 0x00, 0x00, 0x80, 0x01, 0xc0, 0x01, 0xe0, 0x01, 0xb0, 0x11, 0x9e, 0x21, 0x8e, 0x45, 0x86, 0x49, 0x86, 0x49, 0x8e, 0x45, 0x9e, 0x21, 0xb0, 0x11, 0xe0, 0x01, 0xc0, 0x01, 0x80, 0x01, 0x00, 0x00 },
        demoSpeaker
    },
    {
        "OLED",
        "BRIGHTNESS SETTING",
        { 0x00, 0x00, 0x00, 0x00, 0xfe, 0x7f, 0xfe, 0x7f, 0x06, 0x60, 0x06, 0x60, 0x06, 0x60, 0x06, 0x60, 0x06, 0x60, 0xfe, 0x7f, 0xfe, 0x7f, 0x80, 0x01, 0x80, 0x01, 0xf0, 0x0f, 0xf0, 0x0f, 0x00, 0x00 },
        demoOled
    },
    {
        "BUTTON",
        "COUNTING BUTTON PRESSES",
        { 0x00, 0x00, 0xe0, 0x07, 0xe0, 0x07, 0xe0, 0x07, 0xe0, 0x07, 0xfe, 0x7f, 0xfe, 0x7f, 0x06, 0x60, 0x06, 0x60, 0x36, 0x6c, 0xfe, 0x7f, 0xfe, 0x7f, 0x30, 0x0c, 0x30, 0x0c, 0x30, 0x0c, 0x00, 0x00 },
        demoButton
    },
    {
        "ALARM",
        "SEND ALERT",
        { 0x00, 0x00, 0x00, 0x00, 0x00, 0x00, 0xcf, 0x7b, 0xdb, 0xdb, 0x71, 0x8e, 0x63, 0x1e, 0x6f, 0x7e, 0x7e, 0xf6, 0x78, 0xc6, 0x71, 0x8e, 0xdb, 0xdb, 0xde, 0xf3, 0x00, 0x00, 0x00, 0x00, 0x00, 0x00},
        demoAlarm
    },
    {
        "MICROPHONE",
        "MICROPHONE TEST",
        { 0x00, 0x00, 0xc0, 0x03, 0xe0, 0x07, 0x60, 0x06, 0x60, 0x06, 0x60, 0x06, 0x60, 0x06, 0xec, 0x37, 0xcc, 0x33, 0x1c, 0x38, 0xf8, 0x1f, 0xe0, 0x07, 0x80, 0x01, 0x80, 0x01, 0xe0, 0x07, 0xf0, 0x0f },
        demoMic
    },
    {
        "BME280 SENSOR",
        "EXTERNAL SENSOR",
        { 0xe0, 0x00, 0xf0, 0x01, 0x18, 0x03, 0x58, 0x7b, 0x58, 0x03, 0x58, 0x03, 0x58, 0x7b, 0x58, 0x03, 0x58, 0x03, 0x4c, 0x66, 0xe6, 0x0c, 0xf6, 0x0d, 0xe6, 0x6c, 0x0c, 0x06, 0xf8, 0x03, 0xf0, 0x01 },
        demoSensor
    },
    {
        "GPS",
        "LOCATION INFORMATION",
        {0xe0, 0x07, 0xf0, 0x0f, 0x38, 0x1c, 0xcc, 0x33, 0xec, 0x37, 0x6e, 0x76, 0x26, 0x64, 0x66, 0x66, 0xee, 0x77, 0xcc, 0x33, 0x18, 0x18, 0x38, 0x1c, 0x70, 0x0e, 0xe0, 0x07, 0xc0, 0x03, 0x80, 0x01},
        demoGPS
    },
    {
        "STORAGE",
        "SD CARD INFORMATION",
        {0x00, 0x00, 0xc0, 0x1f, 0xe0, 0x3f, 0x70, 0x35, 0x78, 0x35, 0xfc, 0x3f, 0xfc, 0x3f, 0xfc, 0x3f, 0xfc, 0x3f, 0xfc, 0x3f, 0xfc, 0x3f, 0xfc, 0x3f, 0xfc, 0x3f, 0xfc, 0x3f, 0xf8, 0x1f, 0x00, 0x00},
        demoSDCard
    },
    {
        "POWER",
        "POWER MANAGEMENT",
        {0x1e, 0x7a, 0x1f, 0xfb, 0x83, 0xc3, 0xc3, 0xc1, 0xe3, 0xc1, 0xa0, 0x01, 0x90, 0x1f, 0x18, 0x10, 0xfc, 0x09, 0x80, 0x0d, 0x80, 0x07, 0x83, 0xc2, 0x83, 0xc3, 0xc3, 0xc1, 0xdf, 0xf8, 0xde, 0x78},
        demoPMU
    },
    {
        "TRANS FREQ",
        "RADIO TRANS FREQ",
        {0x00, 0x00, 0x00, 0x0c, 0x00, 0x1c, 0x00, 0x3c, 0xc0, 0x7f, 0x30, 0xe0, 0x38, 0xe0, 0xfc, 0x77, 0xee, 0x3f, 0x06, 0x1c, 0x06, 0x0c, 0xfc, 0x03, 0xf8, 0x01, 0x30, 0x00, 0x20, 0x00, 0x00, 0x00},
        demoTransFreq
    },

    {
        "RECV FREQ",
        "RADIO RECV FREQ",
        {0x00, 0x00, 0x00, 0x0c, 0x00, 0x1c, 0x00, 0x3c, 0xc0, 0x7f, 0x30, 0xe0, 0x38, 0xe0, 0xfc, 0x77, 0xee, 0x3f, 0x06, 0x1c, 0x06, 0x0c, 0xfc, 0x03, 0xf8, 0x01, 0x30, 0x00, 0x20, 0x00, 0x00, 0x00},
        demoRecvFreq
    },
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

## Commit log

2022-08-19 feature/at_debug: Add at debug examples
    Bridge to sa868 through esp32, no other operations are required,
    you can directly use serial port tool to debug sa868.
2022-09-06 feature/demo_oled: Add demo_oled examples
    This example provides a visual operation interface through OLED,
    which can make some custom settings for the device.
2022-11-18 fix: Modify the begin method to fix that sa868 cannot be initialized correctly
    [sa868.cpp]
2022-11-18 fix/walkie_talkie: Fix the problem that setting the frequency band is unsuccessful
    [data.cpp, sa868.cpp]
2022-11-21 chore/walkie_talkie: compatible with arduino ide
2022-11-21 feature/walkie_talkie: Display the status of the filter
2023-02-16 Upload schematic file
2023-03-21 Fix high power setting errors and add comments
    [sa868.cpp]
2023-04-22 Fix ArduinoIDE compilation error
2023-05-26 Added TWR Plus schematic
2023-06-08 Update schematic
2023-06-19 Added DXF
    [TWR_Plus_Rev2_0.DXF]
2023-06-21 Added PCB 3D Model
2023-06-21 Added Display Shell
    [TWR-Plus-Display-shell.stp]
2023-12-28 Update tinyUF2 ，Adapt to Rev2.1
2024-01-25 Update boards
2024-01-25 Added Rev2.1 schematic
2024-02-29 Fixed typo & Added Sleep test
    [Factory.ino]
2024-03-05 Added Arduino CI
2024-03-05 Fixed ArduinoCI
2025-08-05 Added disp shell
    [TWR-Plus-Rev2.1-Display-shell.stp]
